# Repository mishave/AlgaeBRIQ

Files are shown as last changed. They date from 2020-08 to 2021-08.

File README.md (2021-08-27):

# BRIQ Algae PBR
Algae photobioreactor(PBR) platform - Focused on algae as potential food sources or means for small scale carbon sequestration, apposed to biofuel, the project hopes to provide the starting point for collaboration, to bring PBR technology out of the lab and into our everyday lives. 

*WORK IN PROGRESS*
<p align="center">
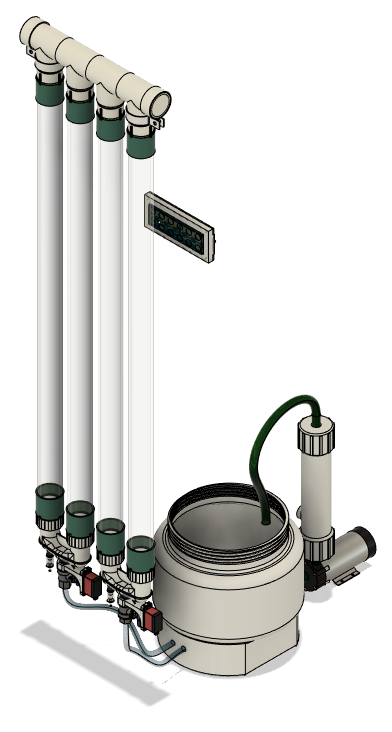
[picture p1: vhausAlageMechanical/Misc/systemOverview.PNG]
  
</p>

## Design Overview :v:
### Cultivation
- Close loop design
- 5.8L capacity
- Sensing: 
  - pH
  - Water Temperature
  - Dissolved Oxygen
  - Lux
  - Water Level
  - External Temperature & Humidity
- Control:
  - pH up/Down
  - Culture Temperature
  - Light Cycle & Intensity

### Harvesting
- 15L capacity
- crossflow filter

### Software
- Home Assistant
  - Mosquitto broker - MQTT
  - AppDaemon - Python
- Google Sheets API

## Next Steps :point_up:
- [ ] Transfer drawings from Eagle to KiCad
- [ ] Add heating to tempreture control
- [ ] Remove Arduino Mega

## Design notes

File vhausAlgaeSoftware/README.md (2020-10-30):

# Vhaus.Tech Algae Software
Software based Home Assistant using RaspberryPi 4.

*WORK IN PROGRESS*

<p align="center">
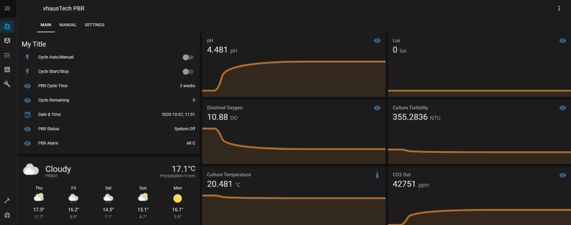
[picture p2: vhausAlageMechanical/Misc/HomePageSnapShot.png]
  
</p>

It is recommended to set up Home Assistant first [Home Assistant Setup Guide](https://github.com/mishave/vhausAlgae/tree/master/vhausAlgaeSoftware/Home%20Assistant%20SetUp)
## Software 
### Setup
The software will require:
- 1 RasberryPi
- 3 ESP32 WROOMS 32D Microcontrollers
- Arduino Mega
- Sensor PCB
- Brain PCB

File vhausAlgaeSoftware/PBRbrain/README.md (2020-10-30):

# Vhaus.Tech Algae Brain
Brains of the operation - The brain ESP board is what houses the code to run routines.

*WORK IN PROGRESS*

## Overview
### Required Parts
- ESP32-WROOMS-32D (ESP_Devkitc_v4)
- Arduino Mega (Looking to make obsolete, in v2.0)

### Software
- Arduino IDE - [Arduino IDE Download Link](https://www.arduino.cc/en/software)

### Required Libraries
#### ESP Board
- ArduinoJson.h
- WiFi.h
- PubSubClient.h
- WiFiManager.h

#### Arduino Mega Board
- ArduinoJson.h
- VarSpeedServo.h

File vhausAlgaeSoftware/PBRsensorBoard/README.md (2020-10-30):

# Vhaus.Tech Algae Sensor
It has a sixth sense - The Sensor board is what reads and communicates the data

*WORK IN PROGRESS*

## Overview
### Required Parts
- ESP32-WROOMS-32D (ESP_Devkitc_v4)

### Software
- Arduino IDE - [Arduino IDE Download Link](https://www.arduino.cc/en/software)

### Required Libraries
#### ESP Board
- SparkFun_Qwiic_Humidity_AHT20.h
- Adafruit_Sensor.h
- Adafruit_TSL2591.h
- SparkFun_Qwiic_Humidity_AHT20.h
- ArduinoJson.h
- WiFi.h
- PubSubClient.h
- WiFiManager.h
- Wire.h
- OneWire.h

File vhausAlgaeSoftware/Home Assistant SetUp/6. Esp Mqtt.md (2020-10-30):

###### 1	Add Esp Boards
Add to Additional Boards Mangaer URLS:
(File>Preferences)
 - https://dl.espressif.com/dl/package_esp32_index.json
Open Boards Manager and Add:
- esp32 by Espressif Systems

###### 2 Add Libraries
Include Libaries - From Library Manager:
 - PubSubClient by Nick
 - PageBuilder by Hieromon Ikasamo
 - WifiManager by tzapu

###### 3 Using The Following Test Code
Make sure you:
 - const char* mqtt_server = "192.168.0.200"; //set to your Home Assistant IP
 - const char *HA_USER = "Your HA Login"; //Set to your Home Assistant Login
 - const char *HA_PASS = "Your HA Password"; //Set to your Home Assistant Password

 Select from Tools your board:
  - ESP32 Dev Module
  - Select Comm Port - plug in and unplug to determine
  - verify and upload

Confirm that it has been uploaded via serial monitor, log with help to confirm it has worked.

```

#include <WiFi.h>
#include <PubSubClient.h>
//needed for library
#include <DNSServer.h>
#include <ESP8266WebServer.h>
#include <WiFiManager.h>         //https://github.com/tzapu/WiFiManager

// MQTT Network
const char* mqtt_server = "192.168.0.200"; //Set to you HA IP. recommend setting home assistant a a static IP
WiFiClient espClient;
PubSubClient client(espClient); // Setup MQTT client
const byte SWITCH_PIN = 0;           // Pin to control the light with
const char *ID = "Moisture_1";  // Name of our device, must be unique
const char *TOPIC = "Moisture_Sensor";  // Topic to subcribe to

bool state = 0;
String switch1;
String strTopic;
String strPayload;
int SwitchedPin = 0;

// Home Assistant Credentials
const char *HA_USER = "Your HA Login";
const char *HA_PASS = "Your HA Password";

// Moisture sensor
const float AirValue = 4095.0;   //you need to replace this value with Value_1
const float WaterValue = 1999.0;  //you need to replace this value with Value_2
const int SensorPin = 15;
float soilMoistureValue = 0.0;
float soilmoisturepercent = 0.0;
int lastreading = 0;
int timervalue = 200;

void setup_wifi() {
  Serial.print("\nConnecting to ");

  //WiFiManager
  //Local intialization. Once its business is done, there is no need to keep it around
  WiFiManager wifiManager;
  Serial.println("started");
  //reset saved settings

  //wifiManager.resetSettings();
  wifiManager.setCustomHeadElement("<style>html{filter: invert(40%); -webkit-filter: invert(40%);}</style>");
  WiFiManagerParameter custom_text("<p>This is just a text paragraph</p>");
  wifiManager.addParameter(&custom_text);
  //set custom ip for portal
  //wifiManager.setAPStaticIPConfig(IPAddress(10,0,1,1), IPAddress(10,0,1,1), IPAddress(255,255,255,0));

  //fetches ssid and pass from eeprom and tries to connect
  //if it does not connect it starts an access point with the specified name
  //here  "AutoConnectAP"
  //and goes into a blocking loop awaiting configuration
  //set custom ip for portal
  wifiManager.setAPStaticIPConfig(IPAddress(100, 100, 100, 100), IPAddress(100, 100, 100, 100), IPAddress(255, 255, 255, 0));
  //wifiManager.setSTAStaticIPConfig(IPAddress(192,168,0,99), IPAddress(192,168,0,1), IPAddress(255,255,255,0));

  wifiManager.autoConnect();
  //or use this for auto generated name ESP + ChipID
  //wifiManager.autoConnect();

  while (WiFi.status() != WL_CONNECTED) { // Wait for connection
    delay(500);
    Serial.print(".");
  }

  //if you get here you have connected to the WiFi
  Serial.println();
  Serial.println("WiFi connected");
  Serial.print("IP address: ");
  Serial.println(WiFi.localIP());
}

// Reconnect to client
void reconnect() {
  // Loop until we're reconnected
  while (!client.connected()) {
    Serial.print("Attempting MQTT connection...");
    // Attempt to connect
    if (client.connect(ID, HA_USER, HA_PASS)) {
      Serial.println("connected");
      Serial.print("Publishing to: ");
      Serial.println(TOPIC);
      Serial.println('\n');

    } else {
      Serial.println(" try again in 5 seconds");
      // Wait 5 seconds before retrying
      delay(5000);
    }
  }
}

void callback(char* topic, byte* payload, unsigned int length) {
  payload[length] = '\0';
  strTopic = String((char*)topic);
  if (strTopic == "ha/switch1")
  {
    switch1 = String((char*)payload);
    if (switch1 == "ON")
    {
      Serial.println("ON");
      digitalWrite(SwitchedPin, HIGH);
    }
    else
    {
      Serial.println("OFF");
      digitalWrite(SwitchedPin, LOW);
    }
  }
}

void setup() {
  // put your setup code here, to run once:
  Serial.begin(115200);

  pinMode(SWITCH_PIN, INPUT); // Configure SWITCH_Pin as an input
  digitalWrite(SWITCH_PIN, HIGH); // enable pull-up resistor (active low)
  delay(100);
  setup_wifi(); // Connect to network
  client.setServer(mqtt_server, 1883);
  client.setCallback(callback);
}

void loop() {
  if (!client.connected()) { // Reconnect if connection is lost
    reconnect();
  }
  client.loop();

  // if the switch is being pressed
  if (digitalRead(SWITCH_PIN) == 0) {

    state = !state; //toggle state
    if (state == 1) {// ON

      //client.publish(TOPIC, "on");
      //Serial.println((String)TOPIC + " => on");
    }
    else {// OFF

      //client.publish(TOPIC, "off");
      //Serial.println((String)TOPIC + " => off");
    }

    while (digitalRead(SWITCH_PIN) == 0) {// Wait for switch to be released

      delay(20);
    }
  }

  moisture_sensor();

}

void moisture_sensor() {

  if (!client.connected())  // Reconnect if connection is lost
  {
    reconnect();
  }
  client.loop();

  soilMoistureValue = 255;
  Serial.println(soilMoistureValue);
  soilmoisturepercent = 100.0 * (soilMoistureValue - AirValue) / (WaterValue - AirValue);   //map(soilMoistureValue, AirValue, WaterValue, 0, 100);

  if (lastreading != soilmoisturepercent) {
    if (soilmoisturepercent > 100)
    {
      soilmoisturepercent = 100;
      lastreading = soilmoisturepercent;
    }
    else if (soilmoisturepercent < 0)
    {
      soilmoisturepercent = 0;
      Serial.println(soilMoistureValue);
    }
    else if (soilmoisturepercent >= 0 && soilmoisturepercent <= 100)
    {
      Serial.print(soilMoistureValue);
    }
  }
  soilmoisturepercent = random(45,100);
  client.publish(TOPIC, String(soilmoisturepercent).c_str());
  Serial.print ("MQTT Published");
}
```
###### 4 Connect ESP to WIFI
With ESP plugged in (suggest using a phone), open wifi and find ESP network and connect.
Will promt a login window, use this to add esp to your wifi network. if window does not pop up, open browser and go to 100.100.100.100

Choose network to connect to and type password. 

Once done it will save the network and password so you can upload code without having to do it again.

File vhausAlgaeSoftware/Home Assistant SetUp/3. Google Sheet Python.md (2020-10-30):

## *** CRED.JSON FILE HAS TO BE LOCATED IN /usr/share/hassio/share and label '/share/youfilename.json)

## 1 Add Google Python Packages tToo Suppervisor:
```
system_packages: []
python_packages:
  - hass-apps
  - gspread
  - oauth2client
  - apiclient
init_commands: []
```
## Setup app.yaml to see your file
you can do this after of before but you need to know what your .py file is to be called as well as your class to be called, for example:
```diff
---                         # At the top of the file, doesnt need to be done each time you make a new setup
upDateSheet:                # this can be called what ever you like
    module: upDateMySheet   # this is what your python file .py has to be named
    class: upDateTheSheet   # this is the class to be called inside the .py
```
## Create your .py file and name the same as the module above i.e upDateMySheet.py
```diff
import appdaemon.plugins.hass.hassapi as hass
import gspread
from oauth2client.service_account import ServiceAccountCredentials
import datetime
import json

#
# description of what your doing
#
# Args:
#

class TurnOffPBR(hass.Hass):

    def initialize(self):
        self.listen_state(self.pbr_off_turn_off,"input_boolean.switch1", new='on', old='off')
        
    def pbr_off_turn_off(self, entity, attribute, old, new, kwargs):
        self.run_in(self.search, 2)
        
        # use creds to create a client to interact with the Google Drive API
        scope = ['https://spreadsheets.google.com/feeds',
                 'https://www.googleapis.com/auth/drive']
        creds = ServiceAccountCredentials.from_json_keyfile_name('/share/NameThisYourCredFileName.json', scope) # change to name of your file
        client = gspread.authorize(creds)
        fmt = '%Y-%m-%d %H:%M:%S'
        d = datetime.datetime.now()
        d_string = d.strftime(fmt)
        
        val1 = self.get_state("input_boolean.switch1")
        val2 = "123"

        sheet = client.open("nameThisyouGoogleSheetName").sheet1   #change to name of your sheet
        
        row = [d_string,val1,val2]
        index = 1
        sheet.insert_row(row, index, value_input_option='USER_ENTERED')

    def search(self, kwargs):
        #self.set_textvalue("input_text.text1", "hello world")
        self.turn_off("input_boolean.switch1")
```
## Note You Need To Set Up Any Entities You Are Calling From Home Assistant
in this case we used `input_boolean.switch1` therefor to use it we need to make sure its in our configuration.yaml file.
```diff
#Boolean Switches to be used as control for system
input_boolean:
  switch1:
    initial: off
```

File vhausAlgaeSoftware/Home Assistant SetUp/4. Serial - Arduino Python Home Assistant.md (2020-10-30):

## For this Code a JSON Libary has been used and will need to be installed to work

## 1 Desktop	
- Install Arduino
    https://www.arduino.cc/en/main/software
    **does not have to be on pi, use what ever computer you will be programing on
- Select Sketch > Include Library > Manage Libraries
- In filter search search: JSON
- Select and install: ArduinoJSON by Benoit Blanchon
## 3 Browser	
- Format/Size/Determin JSON String to be sent using ArduinoJSON assistent
    https://arduinojson.org/v6/assistant/
## 4 Arduino - create and upload to Arduino
Example CODE
```diff
#include <ArduinoJson.h>
#include <SoftwareSerial.h>     //not needed, used to debug
SoftwareSerial portTwo(20, 21); //not needed, used to debug

void setup() {
    Serial.begin(9600);
    portTwo.begin(9600);        //not needed, used to debug
}

void loop() {
    UpdatePi();
    RecievePiUpdate();

void UpdatePi() {
    const size_t capacity = JSON_OBJECT_SIZE(4);
    DynamicJsonDocument doc(capacity);
    long randNumber1 = random(20,30);
    long randNumber2 = random(15,25);
    long randNumber3 = random(20,24);
    long randNumber4 = random(0,14);
	
    doc["b1"] = b3;
    doc["b2"] = randNumber2;
    doc["s1"] = randNumber3;
    doc["s2"] = randNumber4;
	
    serializeJson(doc, Serial);
    Serial.println();
}
	
void RecievePiUpdate() {
    const size_t capacity = JSON_OBJECT_SIZE(4) + 20;
    char json[capacity];
    DynamicJsonDocument doc(capacity);
    deserializeJson(doc, Serial);
    b3 = doc["b3"];
    float b4 = doc["b4"];
    long s3 = doc["s3"];
    long s4 = doc["s4"];
	
    serializeJson(doc, portTwo);  //Used only for debugging to a second arduino, not required
    portTwo.println();            //As above
}
```

## 4 RPI creata a .py file - will require addition libaries in supervisor to access serial
```diff
import appdaemon.plugins.hass.hassapi as hass
import datetime
import time
import serial
import json

class ArduinoPiComms(hass.Hass):
        
    def initialize(self):
        start_time = self.datetime() + datetime.timedelta(seconds=1)
        self.handle = self.run_every(self.run_every_Serial,start_time,1)

    def run_every_Serial(self, kwargs):
        # Call to Home Assistant to turn the porch light on
        ser  = serial.Serial(
        port = '/dev/ttyACM0',
        baudrate = 9600,
        timeout=1,
        parity=serial.PARITY_NONE,
        bytesize=serial.EIGHTBITS,
        stopbits=serial.STOPBITS_ONE
        )

    data = {}
    data = {
        b3:float(self.get_state("input_number.slider1")),
        b4:float(self.get_state("input_number.box1")),
        s3:13518,
        s4:13518,
        }
    data=json.dumps(data)

    if ser.isOpen():
        ser.write(data.encode('ascii'))
        ser.flush()
        try:
            incoming = ser.readline().decode("utf-8")
            doc1 = json.loads(incoming)
            self.set_value('input_number.dummy1', doc1["b1"])
            self.set_value('input_number.dummy2', doc1["b2"])
            self.set_value('input_number.dummy3', doc1["s1"])
            self.set_value('input_number.dummy4', doc1["s2"])
        except Exception as e:
            self.log("Error : try to parse an incomplete message")
            pass
        ser.close()
```
## 5 Include pySerial in Appdaemon
```
system_packages: []
python_packages:
  - hass-apps
  - pyserial
init_commands: []
```
## 6 Tell apps.yaml to run your .py file
you can do this after of before but you need to know what your .py file is to be called as well as your class to be called, for example:
```diff
---                         # At the top of the file, doesnt need to be done each time you make a new setup
ArduinoSerial:                # this can be called what ever you like
    module: ArduinoPiSerial.py   # this is what your python file .py has to be named
    class: ArduinoPiComms   # this is the class to be called inside the .py
```

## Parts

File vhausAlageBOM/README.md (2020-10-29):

# Vhaus.Tech Algae BOM:
https://bit.ly/2G91BCT

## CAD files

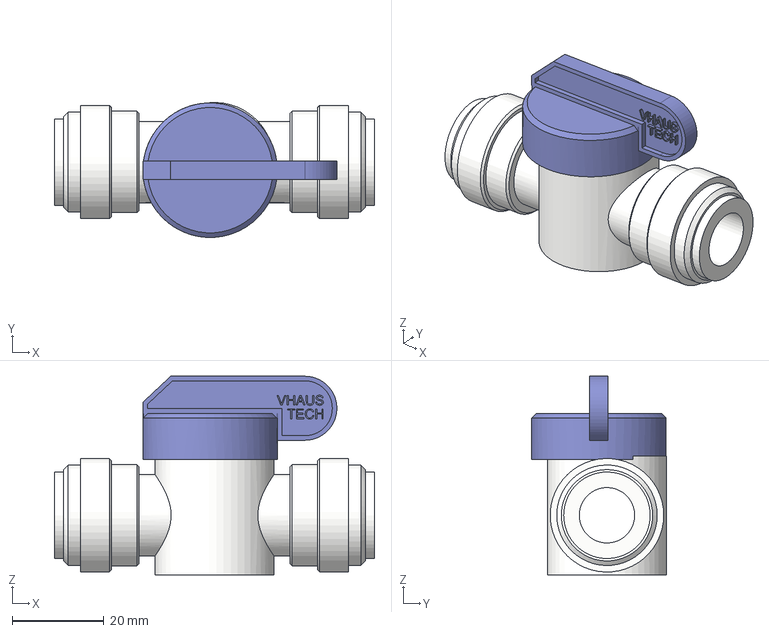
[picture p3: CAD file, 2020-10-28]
vhausAlageMechanical/3D Files/Ball Valves/12MM Shut Off Valve.step
69.9 x 29.5 x 43.4 mm
Base
Top Tap

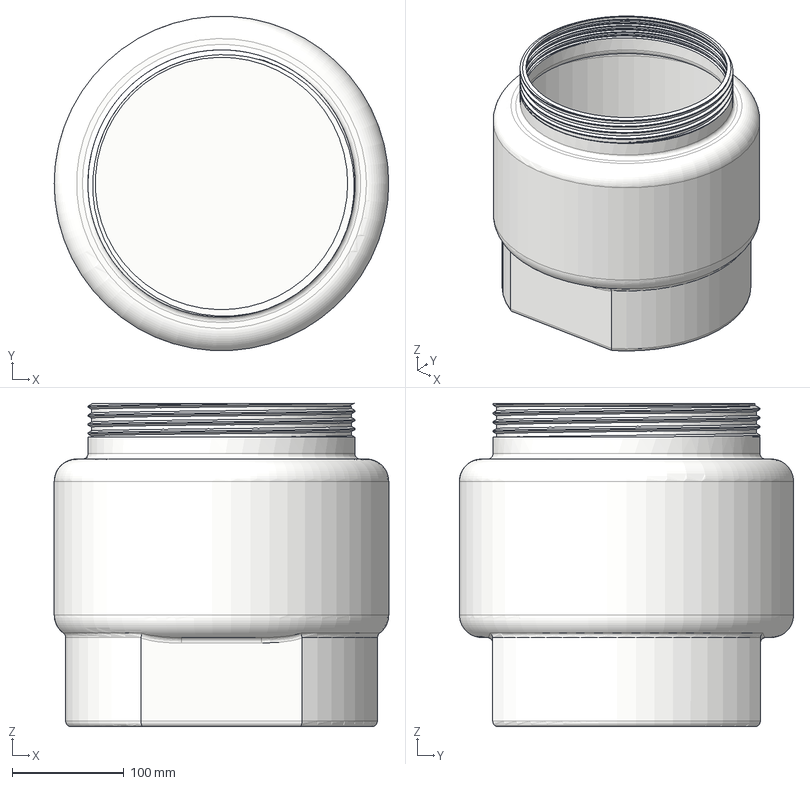
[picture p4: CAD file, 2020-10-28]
vhausAlageMechanical/3D Files/Bio Tube/Tank.step
300.0 x 299.5 x 290.0 mm

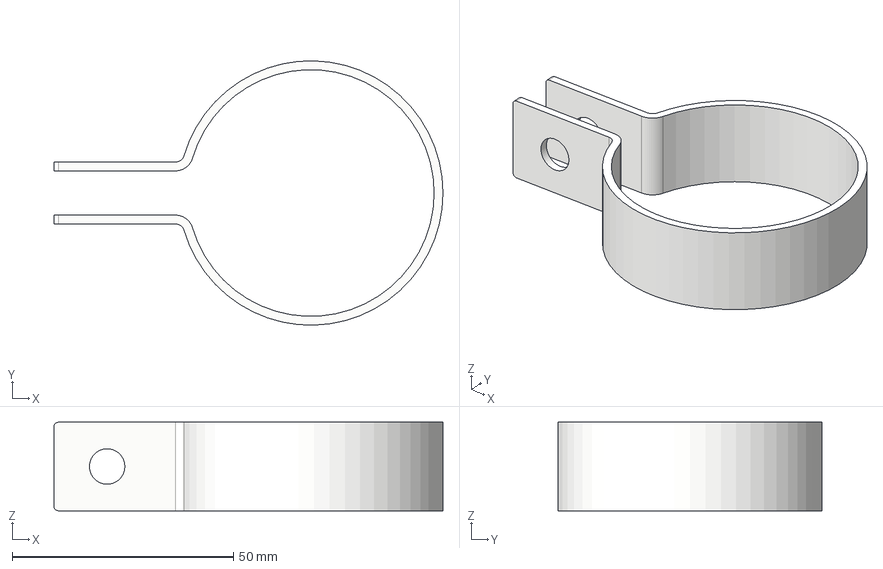
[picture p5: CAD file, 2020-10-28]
vhausAlageMechanical/3D Files/Brackets and Clips/Pipe Clamp.step
87.9 x 59.7 x 20.0 mm

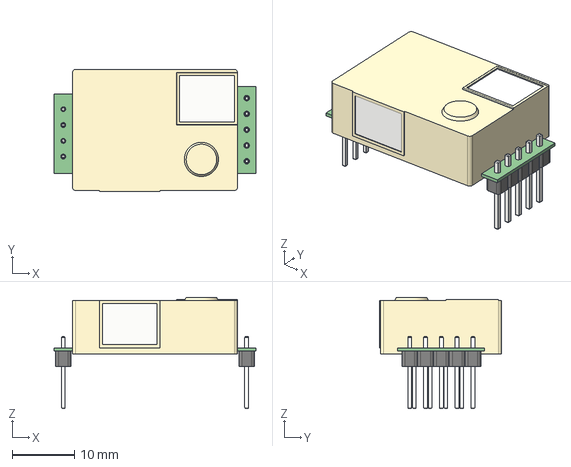
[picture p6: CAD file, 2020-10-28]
vhausAlageMechanical/3D Files/Electrical/MHZ19B.step
32.5 x 19.7 x 17.9 mm
spacer
MHZ19B_1

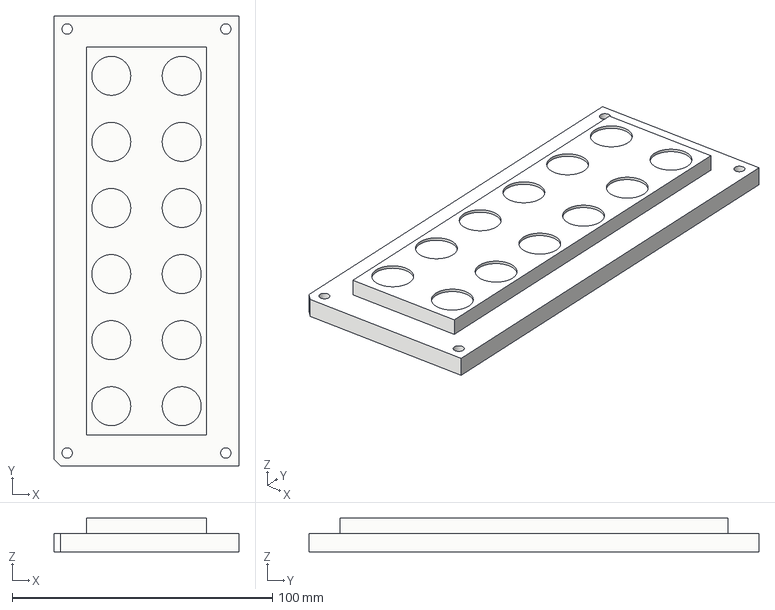
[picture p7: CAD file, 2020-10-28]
vhausAlageMechanical/3D Files/Lighting/Lens.step
71.0 x 173.0 x 13.0 mm

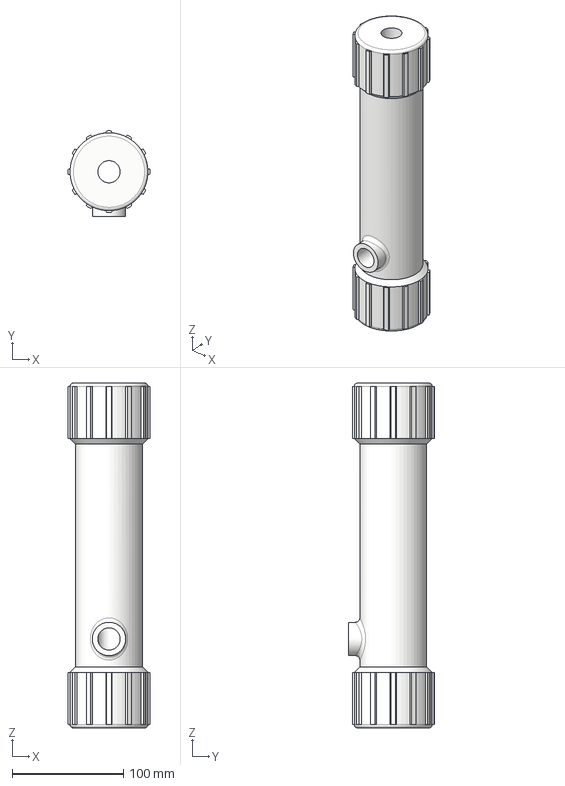
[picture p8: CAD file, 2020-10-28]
vhausAlageMechanical/3D Files/Other/Cross Flow Filter.step
73.7 x 76.8 x 310.0 mm

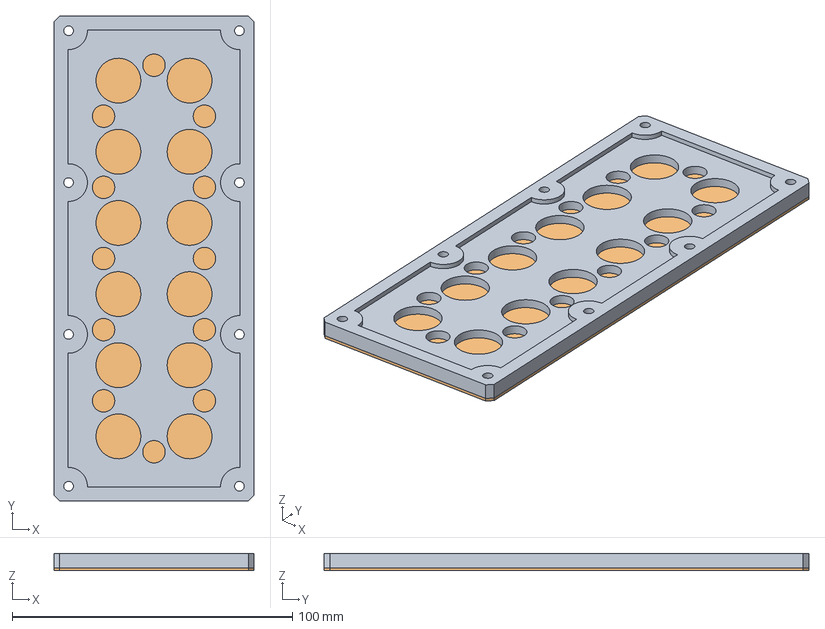
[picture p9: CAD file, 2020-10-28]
vhausAlageMechanical/3D Files/PCBs/LED.step
71.4 x 173.0 x 6.20 mm
Lens
PCB

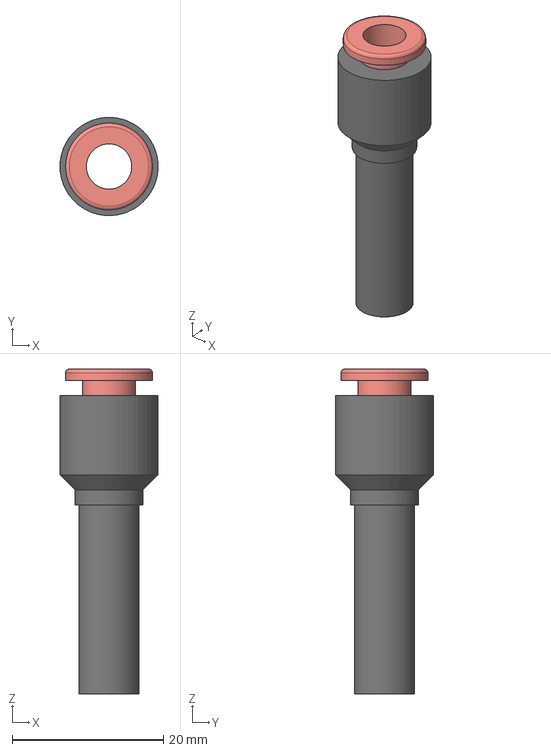
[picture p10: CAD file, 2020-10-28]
vhausAlageMechanical/3D Files/Punematics/Reducer 6-8.step
13.0 x 13.0 x 43.0 mm

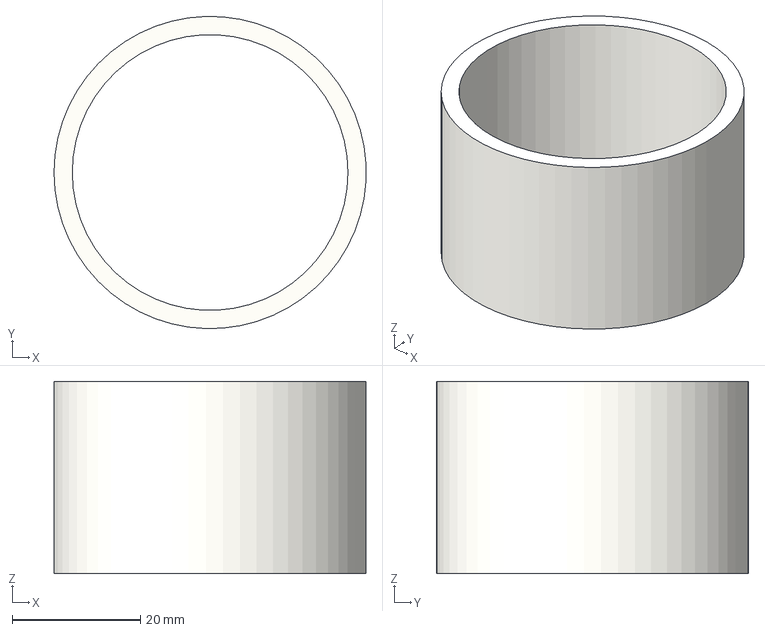
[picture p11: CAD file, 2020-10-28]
vhausAlageMechanical/3D Files/PVC/30mm Spacer - PVC 40mm Pressure Pipe Spacer.step
48.7 x 48.7 x 30.0 mm

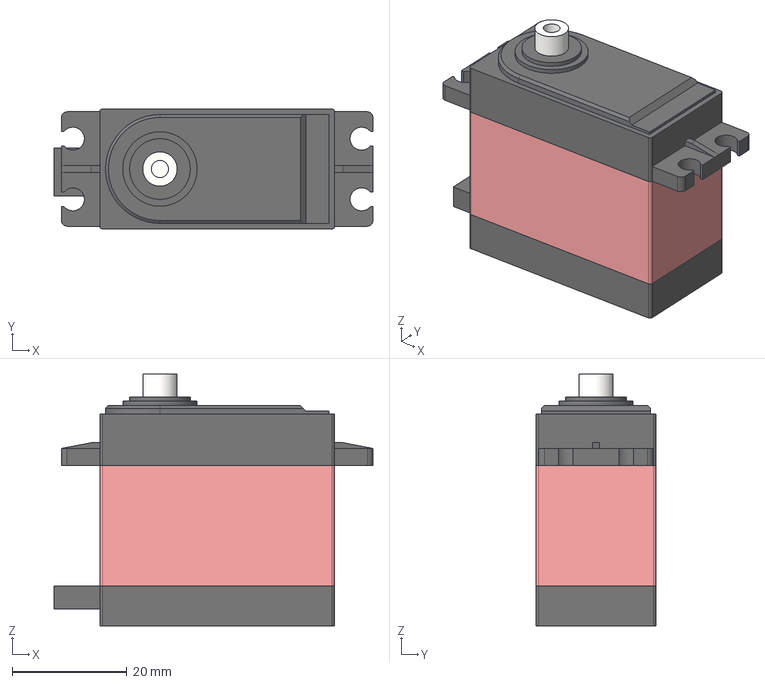
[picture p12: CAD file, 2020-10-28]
vhausAlageMechanical/3D Files/Servo Motors/PowerHD 20Kg 543015.step
55.7 x 21.0 x 44.0 mm

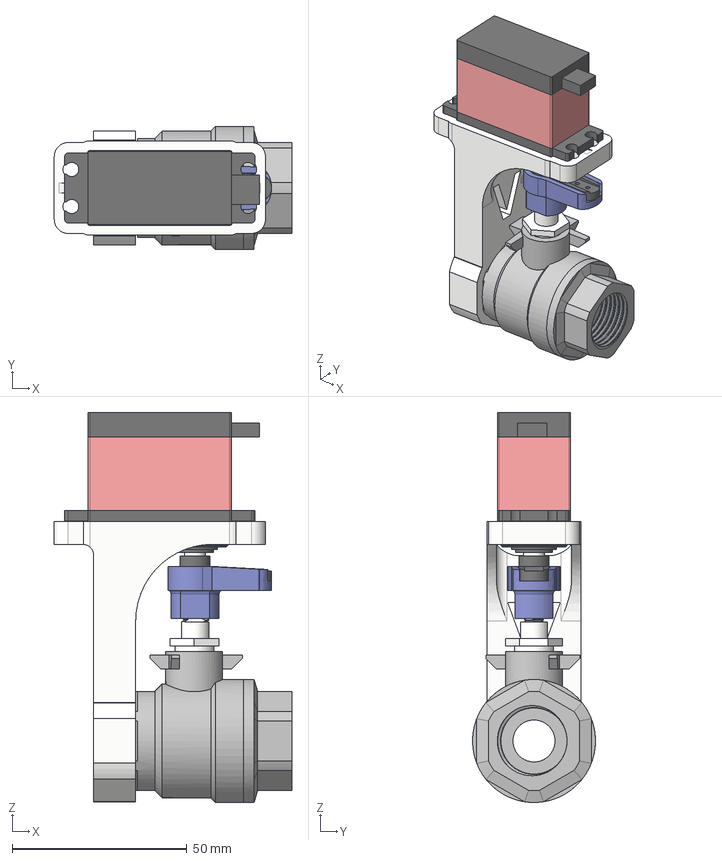
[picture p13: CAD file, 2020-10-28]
vhausAlageMechanical/3D Files/Sub Components/1 2 Flow Control Valve.step
67.9 x 35.2 x 111.5 mm
Servo 20Kg
Single Horn
Main Body
2nd Body
1 2 Horn Shoe
1 2 Main Body

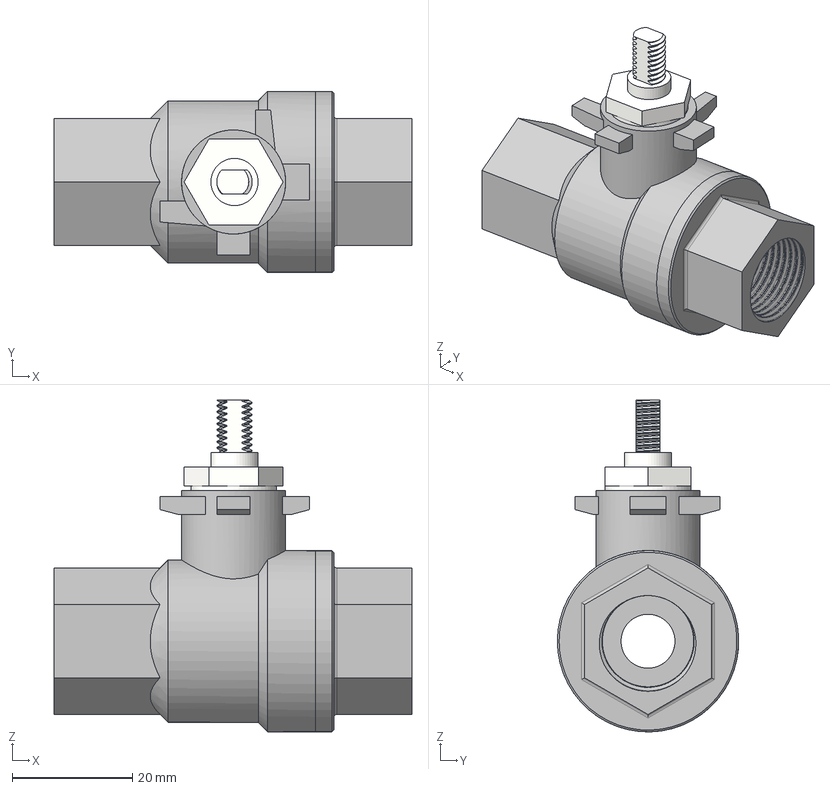
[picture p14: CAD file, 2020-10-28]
vhausAlageMechanical/3D Files/Ball Valves/3 8 Two Piece Ball Valve BVS3B L T.step
59.5 x 30.1 x 55.1 mm
3/8 Two Piece Ball Valve BVS3B-L-T
valve

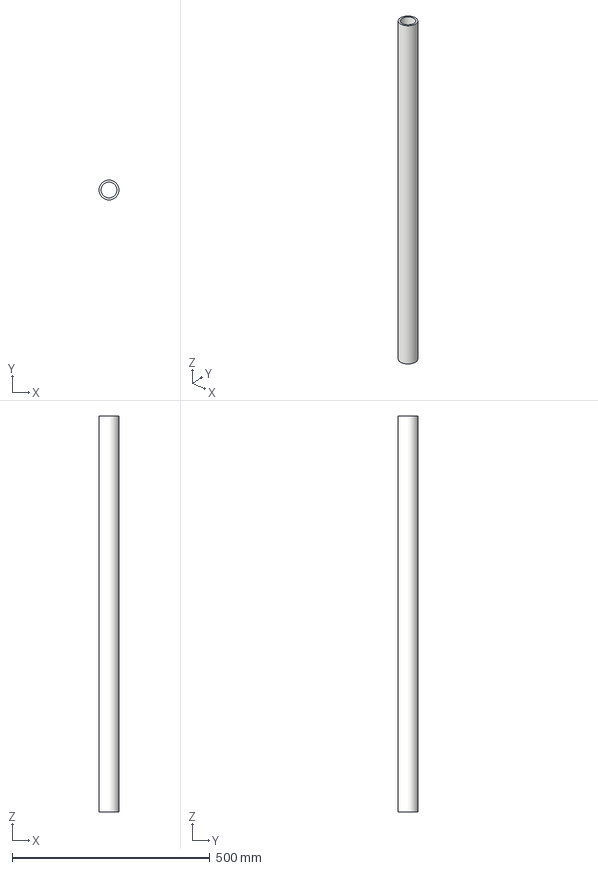
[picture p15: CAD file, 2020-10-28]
vhausAlageMechanical/3D Files/Bio Tube/Bio Tube.step
50.2 x 50.2 x 1000.0 mm

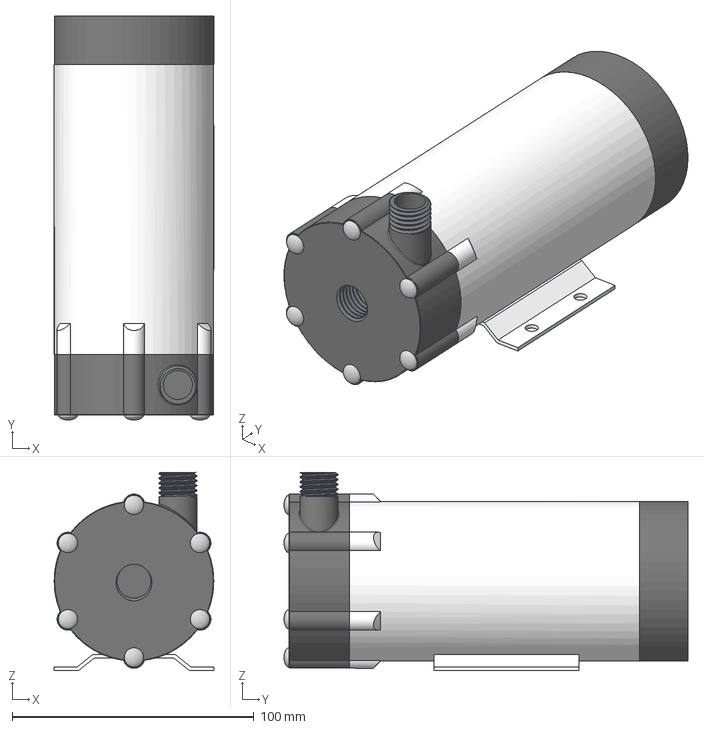
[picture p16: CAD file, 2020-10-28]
vhausAlageMechanical/3D Files/Electrical/Haarvest Pump.step
66.0 x 167.0 x 82.0 mm

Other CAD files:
vhausAlageMechanical/3D Files/PCBs/Sensor Board.step
vhausAlageMechanical/3D Files/Punematics/Check Valve.step
vhausAlageMechanical/3D Files/PVC/DWV PVC Adaptor Male Iron 40mm - Holman.step
vhausAlageMechanical/3D Files/Servo Motors/PowerHD Servo Horn (Half).step
vhausAlageMechanical/3D Files/Ball Valves/1 2 Two Piece Ball Valve BVS4B L T.step
vhausAlageMechanical/3D Files/Electrical/Dosing Pump.step
vhausAlageMechanical/3D Files/PVC/20mm Spacer - PVC 40mm Pressure Pipe Spacer.step
vhausAlageMechanical/3D Files/PVC/40mm DWV female Holman.step
vhausAlageMechanical/3D Files/PVC/40mm Short P Trap PVC Caroma U Bend Only.step
vhausAlageMechanical/3D Files/PVC/50mm End Cap DWV Holman.step
vhausAlageMechanical/3D Files/PVC/PVT 40mm Holman Tee Both Sides Cut.step
vhausAlageMechanical/3D Files/PVC/PVT 40mm Holman Tee One Side Cut.step
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

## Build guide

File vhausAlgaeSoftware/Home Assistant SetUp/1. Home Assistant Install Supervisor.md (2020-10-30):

###### 1	Install RPI OS
See RPI website for info
** add a blank text file to root dir called ssh - this will enable you to access via ssh https://www.raspberrypi.org/documentation/remote-access/ssh/README.md
** for wifi https://www.raspberrypi.org/documentation/configuration/wireless/headless.md
###### 2 Terminal	
`sudo raspi-config`
- Option 5 - Interfacing Options and then enable SSH, VNC, Serial etc.
- Option 7 Advanced Options, and then select Option A1 – expand file system
- Select Finish and reboot when prompted
###### 3 Terminal

```
sudo apt update && sudo apt dist-upgrade -y && sudo apt autoremove -y
sudo reboot
```

###### 4 Terminal

```	
sudo -i
apt-get install -y software-properties-common apparmor-utils apt-transport-https avahi-daemon ca-certificates curl dbus jq network-manager socat
systemctl disable ModemManager
systemctl stop ModemManager
curl -fsSL get.docker.com | sh
curl -sL "https://raw.githubusercontent.com/Kanga-Who/home-assistant/master/supervised-installer.sh" | bash -s -- -m raspberrypi4
```

*** if using a rpi3 replace 4 with 3
###### 5 Browser	
http://192.168.x.x:8123   - use the ip of your rpi
** chaneg to your RPI ip + can take up to 20 mins but once installed signup/login
###### 6 Browser	
***Once logged in and set up
- Open 'Supervisor' in side bar
- Add-on store
- Install AppDaemon 4
- Turn on Start on boot in side bar
- Start AppDaemon
- Install File Editor
- Turn on start on boot and show in side bar
- Start File Editor
	
Developed with the help off	
https://community.home-assistant.io/t/installing-home-assistant-supervised-on-raspberry-pi-os/201836

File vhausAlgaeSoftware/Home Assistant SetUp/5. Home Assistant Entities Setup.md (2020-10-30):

# Entites that can be set up in the configuration.yaml file
## input_boolean
These are used for switches as either on or off - https://www.home-assistant.io/integrations/input_boolean/
```diff
input_boolean:
  Switch1:              #name of entity
    initial: off        #intial state when first turned on
  Switch2:              #name of entity
    name: 2nd Switch    #friendly name that will show up on dashboard inplace of entity name
    icon: mdi:car       #set the icon to something else other then default - see: https://materialdesignicons.com/
    initial: off        #intial state when first turned on
```
when you call and input_boolean it will be address i.e. `input_boolean.Switch1`
In appdeamon this can be called by `self.get_state("input_boolean.pbr_auto_man")` This will return a 'on' or 'off'
to convert to a int/byte you can do the following:
```
Switch1_State = self.get_state("input_boolean.Switch1")
if Switch1_State == 'off':
    Switch1_State=0
else:
    Switch1_State=1
```
In appdaemon you can also set the sate by `self.turn_on('input_boolean.Switch1')` which you would call if a condition was met

## input_number
input_numbers are used to store values - https://www.home-assistant.io/integrations/input_number
these can either be displayed as a box or slider - see below.
This is also how you would make a dummy sensor, where the input_number is what updates the sensor value
```
input_number:
  slider1:
    name: Slider
    initial: 0
    min: 0
    max: 255
    step: 1
  box1:
    name: Numeric Input Box
    initial: 22
    min: -20
    max: 99
    step: 0.1
    mode: box
```
the minimum requirements are:
```
input_number:
  Slider1:
    min: -10
    max: 99
```
In appdaemon you can get the value using get state i.e `self.get_state("input_number.Slider1")` to convert from a string to a float for serial you can call `float(self.get_state("input_number.Slider1"))`
and like wise to set the value you can call `self.set_value('input_number.Slider1')`
** See 4. Serial - Arduino Python Home Assistant.md for more detail and use

## Sensors
Used to diplay your data on a chart etc. - https://www.home-assistant.io/integrations/sensor
```
sensor:
  - platform: template
    sensors:
      sensor1:
        friendly_name: "Water Sensor"
        value_template:"{{ states('input_number.Slider1') }}"
```
In the example above as the sensor is called from the input_number you do not need to use this in appdaemon, but weould follow the same process if needed.

###### To display a sensor in a time format you can add the following to the value template:

```diff
# NOTE:
# - define durations for the various UNITs of time
#   * modulus helps to reduce ""extras"" of the larger time units
# 
# - now build the string
#
# for each UNIT of time that's greater than 1:
#     if it's not the first loop iteration:
#         append "", "" to the string
#     else:
#         1. convert the DURATION to STR
#         2. split DURATION on "".""
#         3. append the left part (the whole number) to the string
#         4. append the UNIT to the string
#
# ...but if that's no UNITs, then we just started so
# set the string to ""just now""
#

sensor:
  - platform: template
    sensors:
#main Panel
      TimeInput:
        friendly_name: "Time"
        value_template: >-
          {%- set uptime  = states.input_number.TimeInput | round -%}
          {%- set sep     = ', ' -%}
          {%- set TIME_MAP = {
              'week': (uptime / 10080) % 10080,
               'day': (uptime / 1440) % 7,
              'hour': (uptime / 60) % 24,
            'minute': (uptime % 60)
          }
          -%}

          {%- for unit, duration in TIME_MAP.items() if duration >= 1 -%}
            {%- if not loop.first -%}
              {{ sep }}
            {%- endif -%}
              
            {{ (duration | string).split('.')[0] }} {{ unit }}

            {%- if duration >= 2 -%}
              s
            {%- endif -%}
          {%- endfor -%}

          {%- if uptime < 1 -%}
            0
          {%- endif -%}
```

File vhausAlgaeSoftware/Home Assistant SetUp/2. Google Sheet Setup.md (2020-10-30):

## Prerequisites:					
- Python 2.6 or greater - https://www.python.org/		
- The pip package management tool - https://pypi.org/project/pip/		
- A Google account - gmail/gsuite		
					
## 1 Terminal					
```
sudo pip install pip
sudo apt update && sudo apt dist-upgrade -y && sudo apt autoremove -y
sudo reboot
```	
## 2 Terminal					
`sudo pip install --upgrade google-api-python-client google-auth-httplib2 google-auth-oauthlib`			
					
## 3 Browser					
***Sign up if you havent already 				
- https://console.developers.google.com/				
- Select Create Project				
***Give project a name etc.				
- in search bar 'search for apis and services' search and enable the following:				
- Google Sheets API				
- Google Drive API				
					
- Use the home navigation icon in the top left and open 				
- APIs and Services > Credentials				
- .+Create Creditials				
- select Service Account				

	Role > Project > Editior				

	Leave blank and hit done				

	click on email name				

	Click Add Key > Create new Key				

	Select JSON and click CREATE				

	It will save a .JSON file to your computer, re name this and store it in the same dir where you will be running your python script from. If unkown save it in a safe place for later				
					
## 4 Browser					
- Create a new spread sheet and save it				
- Copy Service account email and share spread sheet (allow email to edit etc.)

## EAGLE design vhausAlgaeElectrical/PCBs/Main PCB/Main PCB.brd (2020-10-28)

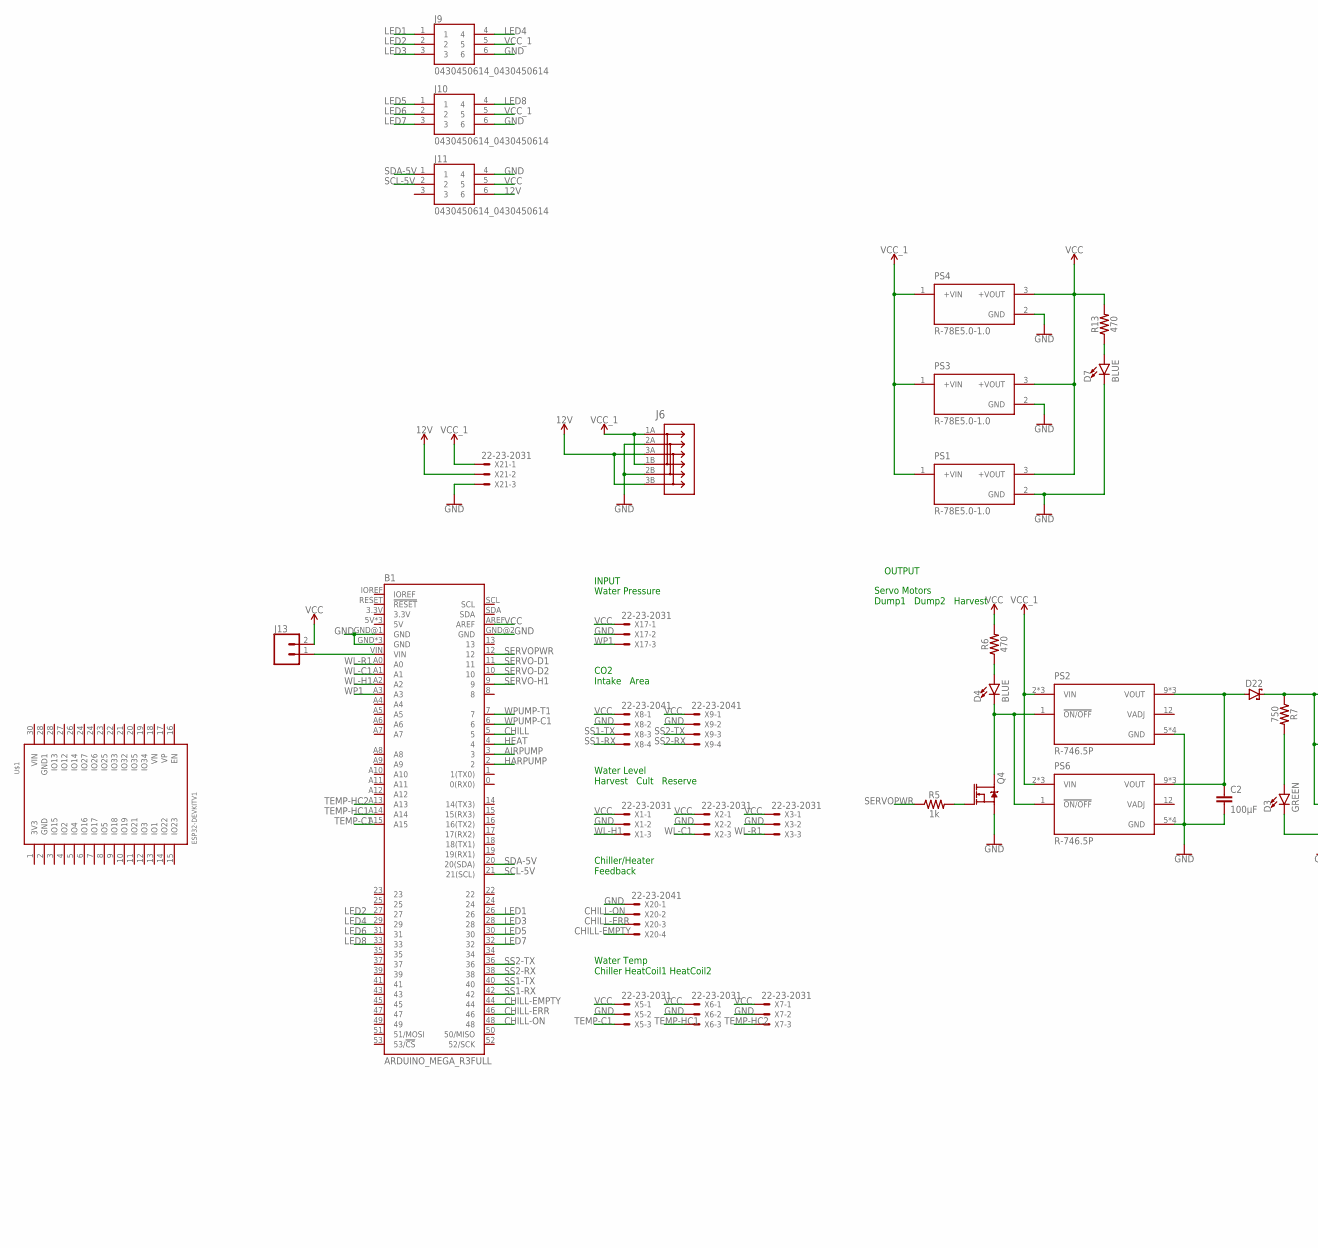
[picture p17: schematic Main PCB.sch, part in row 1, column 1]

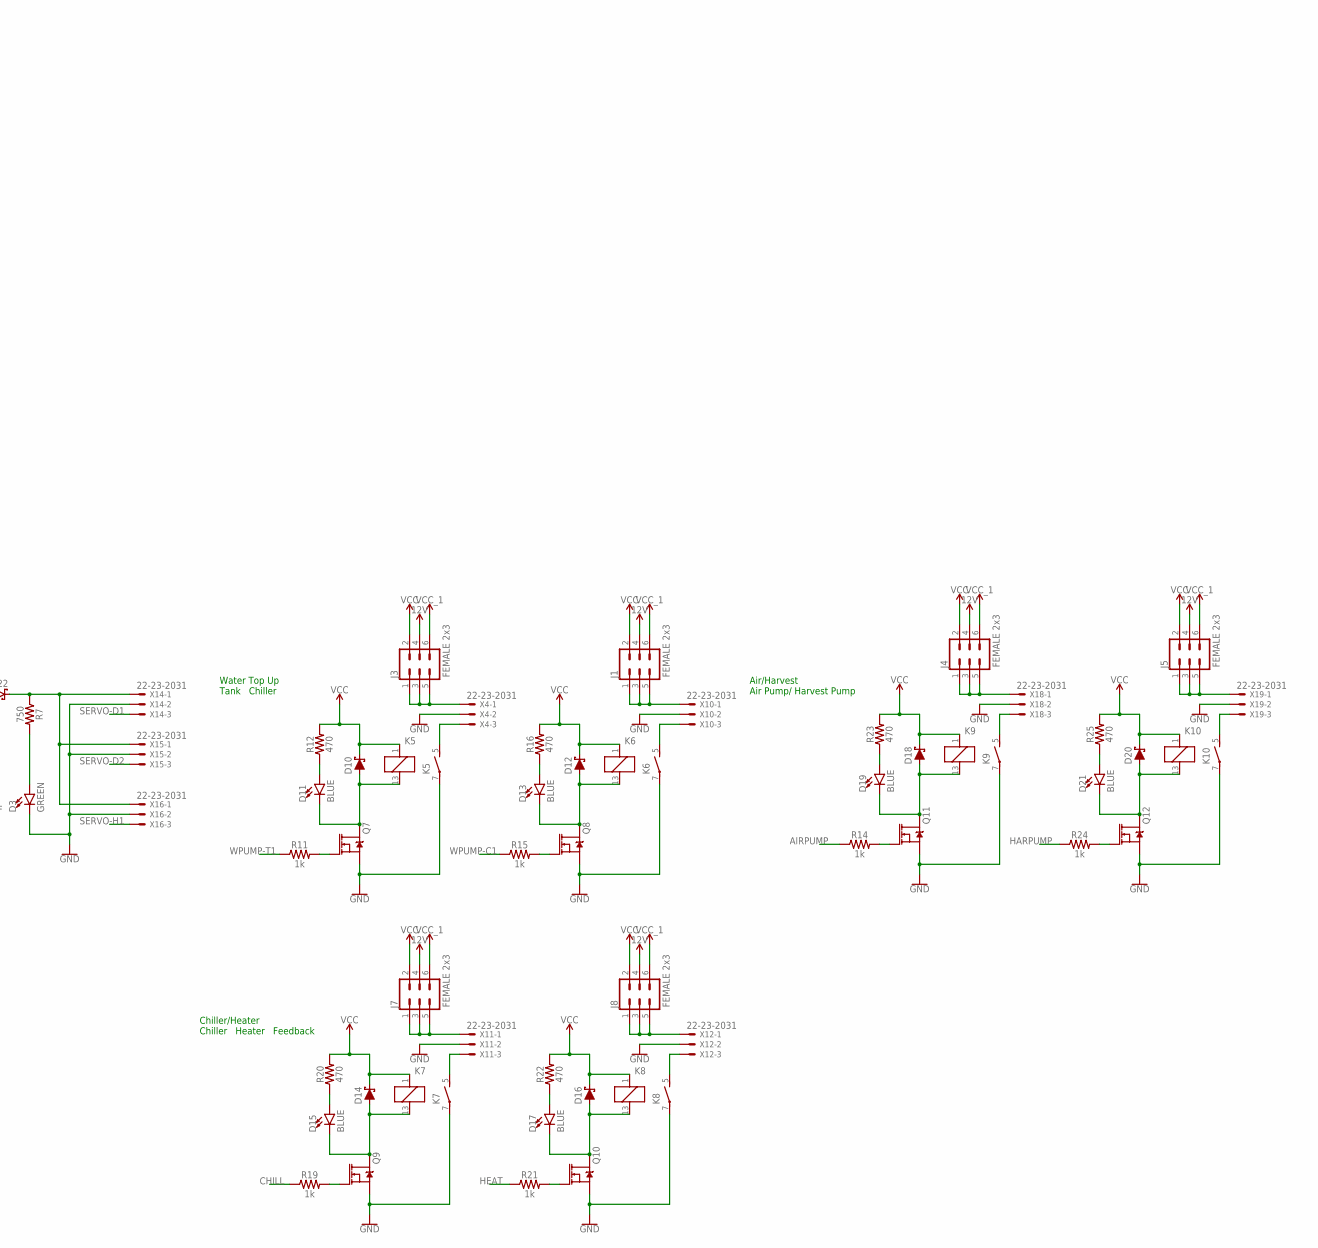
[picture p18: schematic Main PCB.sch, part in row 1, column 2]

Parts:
B1: ARDUINO_MEGA_R3FULL; ARDUINO_MEGA_NO_SILK
C2: 100µF; 0603
D3: GREEN; LED-0603
D4, D7, D11, D13, D15, D17, D19, D21: BLUE; LED-0603
D10, D12, D14, D16, D18, D20: 1A/23V/620mV; SOD-323
D22: SBRT20M60SP5-7SBRT20; DIO_PDS360-13
J1, J3, J4, J5, J7, J8: FEMALE 2x3; 2X3
J6: 1986711-3; CONN3_1986711-3_TEC
J9, J10, J11: 0430450614_0430450614; 0430450614_MOLEX_0430450614
J13: CONN_02; 1X02
K5, K6, K7, K8, K9, K10: G6D-1A-ASI5VDC; G6D
PS1, PS3, PS4: R-78E5.0-1.0; CONV_R-78E5.0-1.0
PS2, PS6: R-746.5P; CONV_R-746.5P
Q4, Q7, Q8, Q9, Q10, Q11, Q12: 220mA/50V/3.5Ω; SOT23-3
R5, R11, R14, R15, R19, R21, R24: 1k; 0603
R6, R12, R13, R16, R20, R22, R23, R25: 470; 0603
R7: 750; 0603
U$1: ESP32DEVKITV1; ESP32-DEVKITV1
X1, X2, X3, X4, X5, X6, X7, X10, X11, X12, X14, X15, X16, X17, X18, X19, X21: 22-23-2031
X8, X9, X20: 22-23-2041

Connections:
12V: J1.4, J3.4, J4.4, J5.4, J6.3A, J6.3B, J7.4, J8.4, J11.6, X21.2
AIRPUMP: B1.3, R14.1
CHILL: B1.5, R19.1
CHILL-EMPTY: B1.44, X20.4
CHILL-ERR: B1.46, X20.3
CHILL-ON: B1.48, X20.2
GND: B1.GND, B1.GND@1 (GND), B1.GND@2 (GND), B1.GND@3 (GND), B1.GND@4 (GND), C2.2, D3.C, D7.C, J6.2A, J6.2B, J9.6, J10.6, J11.4, K5.7, K6.7, K7.7, K8.7, K9.7, K10.7, PS1.2 (GND), PS2.5 (GND), PS2.6 (GND), PS2.7 (GND), PS2.8 (GND), PS3.2 (GND), PS4.2 (GND), PS6.5 (GND), PS6.6 (GND), PS6.7 (GND), PS6.8 (GND), Q4.2 (S), Q7.2 (S), Q8.2 (S), Q9.2 (S), Q10.2 (S), Q11.2 (S), Q12.2 (S), X1.2, X2.2, X3.2, X4.2, X5.2, X6.2, X7.2, X8.2, X9.2, X10.2, X11.2, X12.2, X14.2, X15.2, X16.2, X17.2, X18.2, X19.2, X20.1, X21.3
HARPUMP: B1.2, R24.1
HEAT: B1.4, R21.1
LED1: B1.26, J9.1
LED2: B1.27, J9.2
LED3: B1.28, J9.3
LED4: B1.29, J9.4
LED5: B1.30, J10.1
LED6: B1.31, J10.2
LED7: B1.32, J10.3
LED8: B1.33, J10.4
unnamed: B1.VIN, J13.1
unnamed: D4.C, PS2.1 (!ON/OFF), PS6.1 (!ON/OFF), Q4.3 (D)
unnamed: D4.A, R6.1
unnamed: Q4.1 (G), R5.2
unnamed: D3.A, R7.2
unnamed: D22.3 (C), R7.1, X14.1, X15.1, X16.1
unnamed: J1.1, J1.3, J1.5, X10.1
unnamed: J3.1, J3.3, J3.5, X4.1
unnamed: K8.5 (S), X12.3
unnamed: J4.1, J4.3, J4.5, X18.1
unnamed: J5.1, J5.3, J5.5, X19.1
unnamed: D10.A, D11.C, K5.13 (2), Q7.3 (D)
unnamed: D11.A, R12.1
unnamed: Q7.1 (G), R11.2
unnamed: D12.A, D13.C, K6.13 (2), Q8.3 (D)
unnamed: D13.A, R16.1
unnamed: Q8.1 (G), R15.2
unnamed: D14.A, D15.C, K7.13 (2), Q9.3 (D)
unnamed: D15.A, R20.1
unnamed: Q9.1 (G), R19.2
unnamed: D16.A, D17.C, K8.13 (2), Q10.3 (D)
unnamed: D17.A, R22.1
unnamed: Q10.1 (G), R21.2
unnamed: K7.5 (S), X11.3
unnamed: J7.1, J7.3, J7.5, X11.1
unnamed: D7.A, R13.1
unnamed: K5.5 (S), X4.3
unnamed: K6.5 (S), X10.3
unnamed: C2.1, D22.1 (A), D22.2 (A), PS2.9 (VOUT), PS2.10 (VOUT), PS2.11 (VOUT), PS6.9 (VOUT), PS6.10 (VOUT), PS6.11 (VOUT)
unnamed: J8.1, J8.3, J8.5, X12.1
unnamed: D18.A, D19.C, K9.13 (2), Q11.3 (D)
unnamed: D19.A, R23.1
unnamed: Q11.1 (G), R14.2
unnamed: D20.A, D21.C, K10.13 (2), Q12.3 (D)
unnamed: D21.A, R25.1
unnamed: Q12.1 (G), R24.2
unnamed: K10.5 (S), X19.3
unnamed: K9.5 (S), X18.3
SCL-5V: B1.21 (21(SCL)), J11.2
SDA-5V: B1.20 (20(SDA)), J11.1
SERVO-D1: B1.11, X14.3
SERVO-D2: B1.10, X15.3
SERVO-H1: B1.9, X16.3
SERVOPWR: B1.12, R5.1
SS1-RX: B1.42, X8.4
SS1-TX: B1.40, X8.3
SS2-RX: B1.38, X9.4
SS2-TX: B1.36, X9.3
TEMP-C1: B1.A15, X5.3
TEMP-HC1: B1.A14, X6.3
TEMP-HC2: B1.A13, X7.3
VCC: B1.AREF, D10.C, D12.C, D14.C, D16.C, D18.C, D20.C, J1.2, J3.2, J4.2, J5.2, J7.2, J8.2, J11.5, J13.2, K5.1, K6.1, K7.1, K8.1, K9.1, K10.1, PS1.3 (+VOUT), PS3.3 (+VOUT), PS4.3 (+VOUT), R6.2, R12.2, R13.2, R16.2, R20.2, R22.2, R23.2, R25.2, X1.1, X2.1, X3.1, X5.1, X6.1, X7.1, X8.1, X9.1, X17.1
VCC_1: J1.6, J3.6, J4.6, J5.6, J6.1A, J6.1B, J7.6, J8.6, J9.5, J10.5, PS1.1 (+VIN), PS2.2 (VIN), PS2.3 (VIN), PS2.4 (VIN), PS3.1 (+VIN), PS4.1 (+VIN), PS6.2 (VIN), PS6.3 (VIN), PS6.4 (VIN), X21.1
WL-C1: B1.A1, X2.3
WL-H1: B1.A2, X1.3
WL-R1: B1.A0, X3.3
WP1: B1.A3, X17.3
WPUMP-C1: B1.6, R15.1
WPUMP-T1: B1.7, R11.1

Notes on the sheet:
Water Level Harvest Cult Reserve
Water Top Up Tank Chiller
Water Temp Chiller HeatCoil1 HeatCoil2
CO2 Intake Area
Servo Motors Dump1 Dump2 Harvest
Water Pressure
INPUT
OUTPUT
Chiller/Heater Feedback
Chiller/Heater Chiller Heater Feedback
Air/Harvest Air Pump/ Harvest Pump

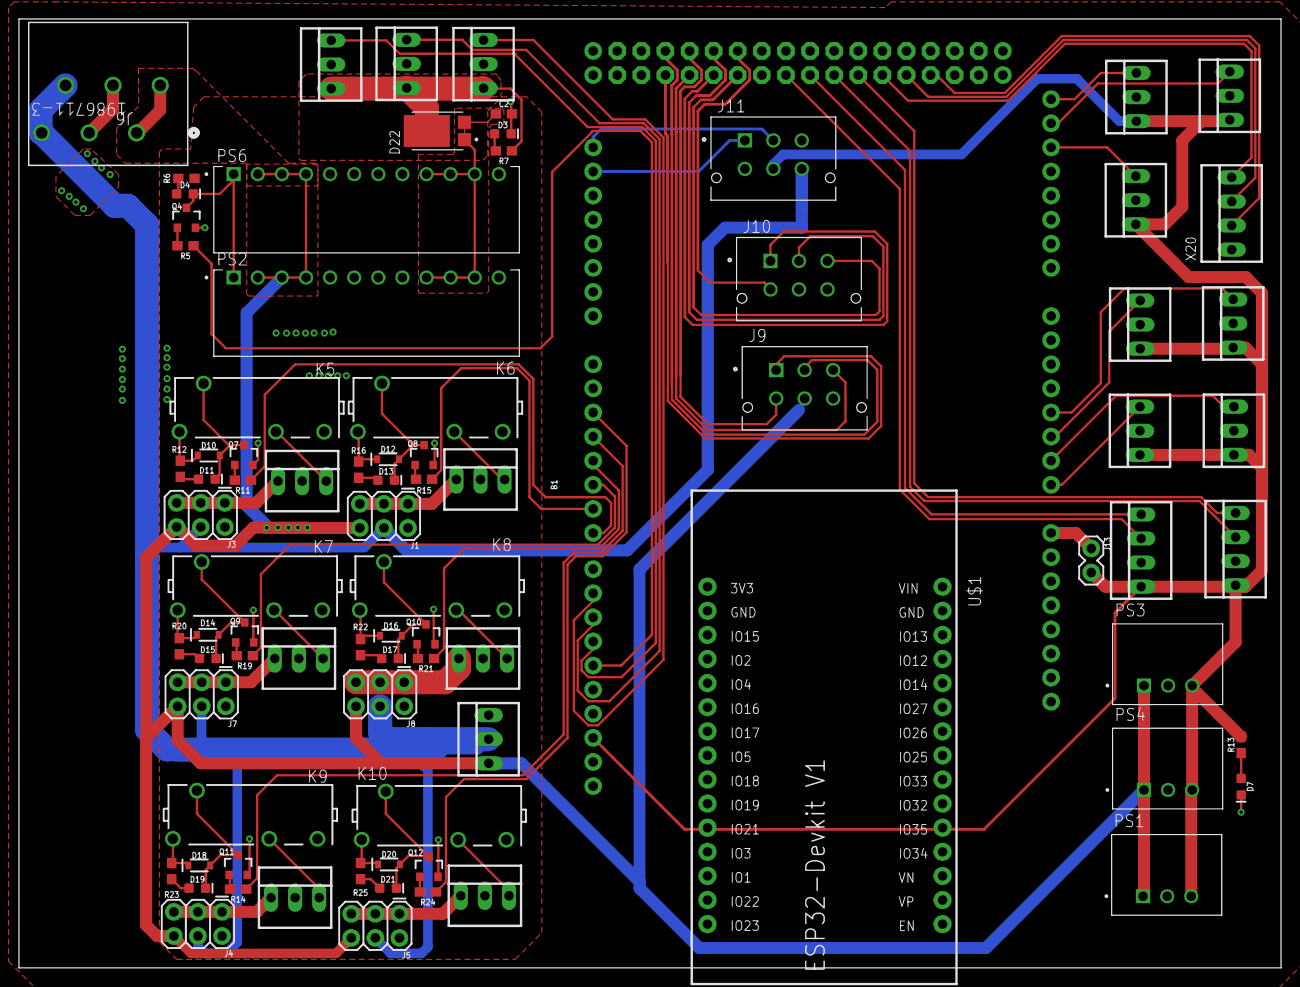
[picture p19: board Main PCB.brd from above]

Board: 2 copper layers, 133.0 x 100.0 mm, 84 parts (0 on the bottom side), 76 nets.

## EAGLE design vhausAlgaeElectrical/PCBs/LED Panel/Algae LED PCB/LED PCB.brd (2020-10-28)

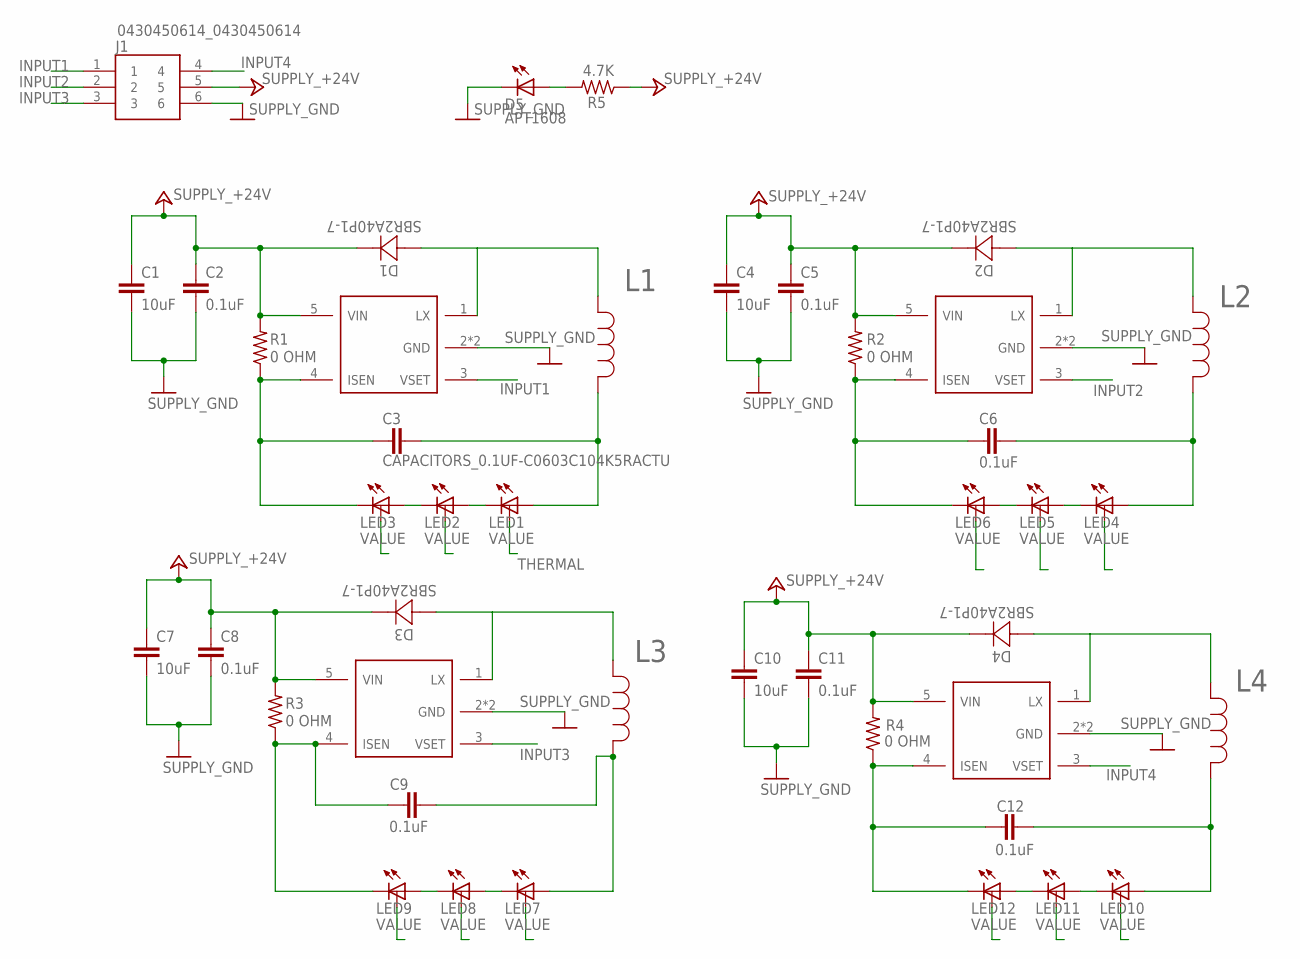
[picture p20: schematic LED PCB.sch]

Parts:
C1, C4, C7, C10: 10uF; CAPACITORS_C0805
C2, C5, C6, C8, C9, C11, C12: 0.1uF; CAPACITORS_C0603
C3: CAPACITORS_0.1UF-C0603C104K5RACTU; CAPACITORS_C0603
D1, D2, D3, D4: SBR2A40P1-7; DIODES_POWERDI123
D5: APT1608; DIODES_CHIPLED_0603
J1: 0430450614_0430450614; 0430450614_MOLEX_0430450614
L1, L2, L3, L4: INDUCTORS_100UH_BOURNES; INDUCTORS_IND_BOURNS_SDR1307
LED1, LED3, LED4, LED5, LED6, LED7, LED8, LED9, LED10, LED11, LED12: PFCEDU_V4_TOMASZEWSKI_LED_W/THERM-CREE_XP-E2; TOMASZEWSKI_CREE-XLAMP@1
LED2: TOMASZEWSKI_LED_W/THERM-CREE_XP-E2; TOMASZEWSKI_CREE-XLAMP@1
R1, R2, R3, R4: 0 OHM; RESISTORS_RC0603N
R5: 4.7K; RESISTORS_R1206
U$1, U$3, U$5, U$7: DRIVER-IC_AL8861

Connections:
+24V: C1.1, C2.1, C4.1, C5.1, C7.1, C8.1, C10.1, C11.1, D1.-, D2.-, D3.-, D4.-, J1.5, R1.2, R2.2, R3.2, R4.2, R5.1, U$1.5 (VIN), U$3.5 (VIN), U$5.5 (VIN), U$7.5 (VIN)
GND: C1.2, C2.2, C4.2, C5.2, C7.2, C8.2, C10.2, C11.2, D5.C, J1.6, U$1.2 (GND), U$1.44 (GND), U$3.2 (GND), U$3.44 (GND), U$5.2 (GND), U$5.44 (GND), U$7.2 (GND), U$7.44 (GND)
INPUT1: J1.1, U$1.3 (VSET)
INPUT2: J1.2, U$3.3 (VSET)
INPUT3: J1.3, U$5.3 (VSET)
INPUT4: J1.4, U$7.3 (VSET)
unnamed: C3.1, LED3.C, LED3.C@1 (C), R1.1, U$1.4 (ISEN)
unnamed: D1.+, L1.2, U$1.1 (LX)
unnamed: C9.2, L3.1, LED7.A, LED7.A@1 (A)
unnamed: C3.2, L1.1, LED1.A, LED1.A@1 (A)
unnamed: LED2.C, LED2.C@1 (C), LED3.A, LED3.A@1 (A)
unnamed: LED1.C, LED1.C@1 (C), LED2.A, LED2.A@1 (A)
unnamed: D3.+, L3.2, U$5.1 (LX)
unnamed: LED5.C, LED5.C@1 (C), LED6.A, LED6.A@1 (A)
unnamed: LED4.C, LED4.C@1 (C), LED5.A, LED5.A@1 (A)
unnamed: C12.1, LED12.C, LED12.C@1 (C), R4.1, U$7.4 (ISEN)
unnamed: D4.+, L4.2, U$7.1 (LX)
unnamed: LED8.C, LED8.C@1 (C), LED9.A, LED9.A@1 (A)
unnamed: LED7.C, LED7.C@1 (C), LED8.A, LED8.A@1 (A)
unnamed: LED11.C, LED11.C@1 (C), LED12.A, LED12.A@1 (A)
unnamed: LED10.C, LED10.C@1 (C), LED11.A, LED11.A@1 (A)
unnamed: C6.1, LED6.C, LED6.C@1 (C), R2.1, U$3.4 (ISEN)
unnamed: D2.+, L2.2, U$3.1 (LX)
unnamed: C6.2, L2.1, LED4.A, LED4.A@1 (A)
unnamed: C12.2, L4.1, LED10.A, LED10.A@1 (A)
unnamed: C9.1, LED9.C, LED9.C@1 (C), R3.1, U$5.4 (ISEN)
unnamed: D5.A, R5.2
THERMAL: LED1.THERM

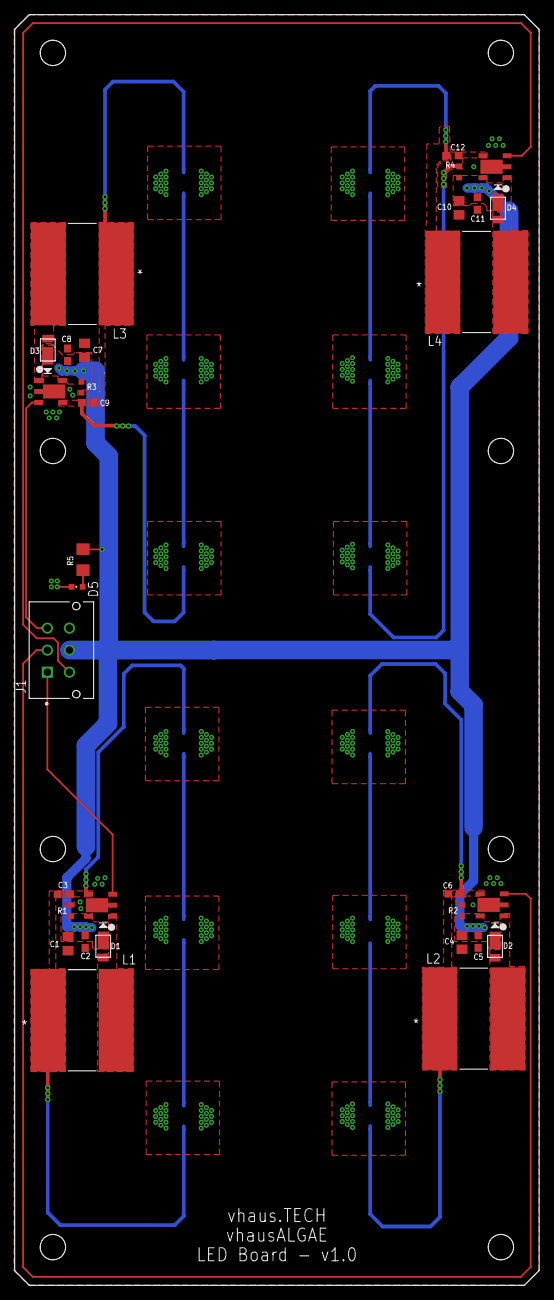
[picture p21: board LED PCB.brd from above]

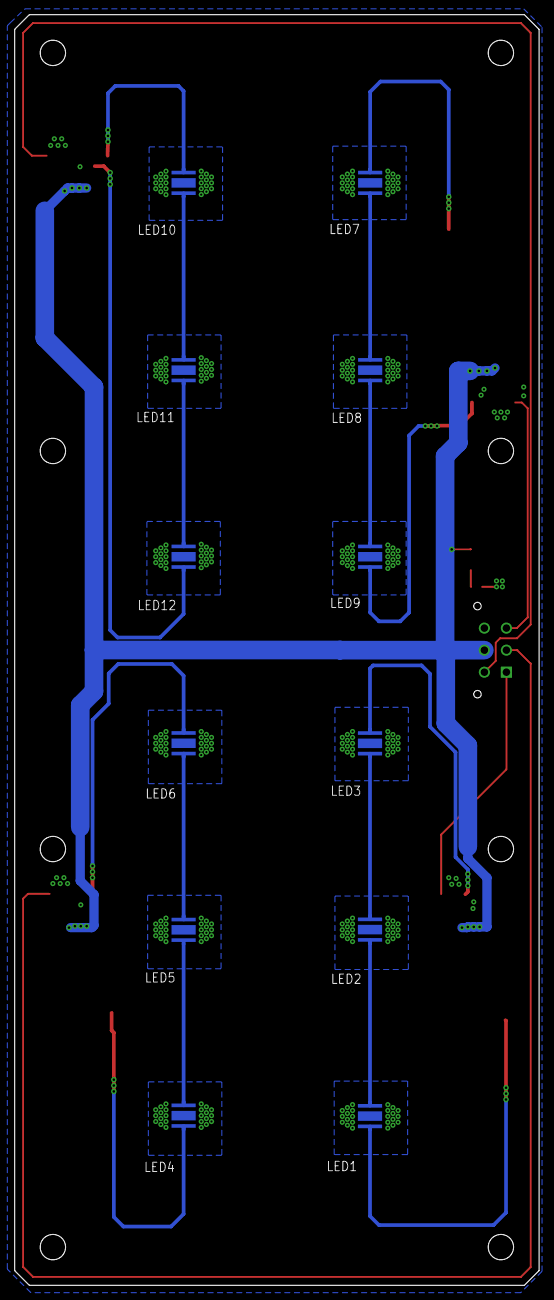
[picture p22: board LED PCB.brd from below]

Board: 2 copper layers, 71.4 x 173.0 mm, 43 parts (12 on the bottom side), 27 nets.

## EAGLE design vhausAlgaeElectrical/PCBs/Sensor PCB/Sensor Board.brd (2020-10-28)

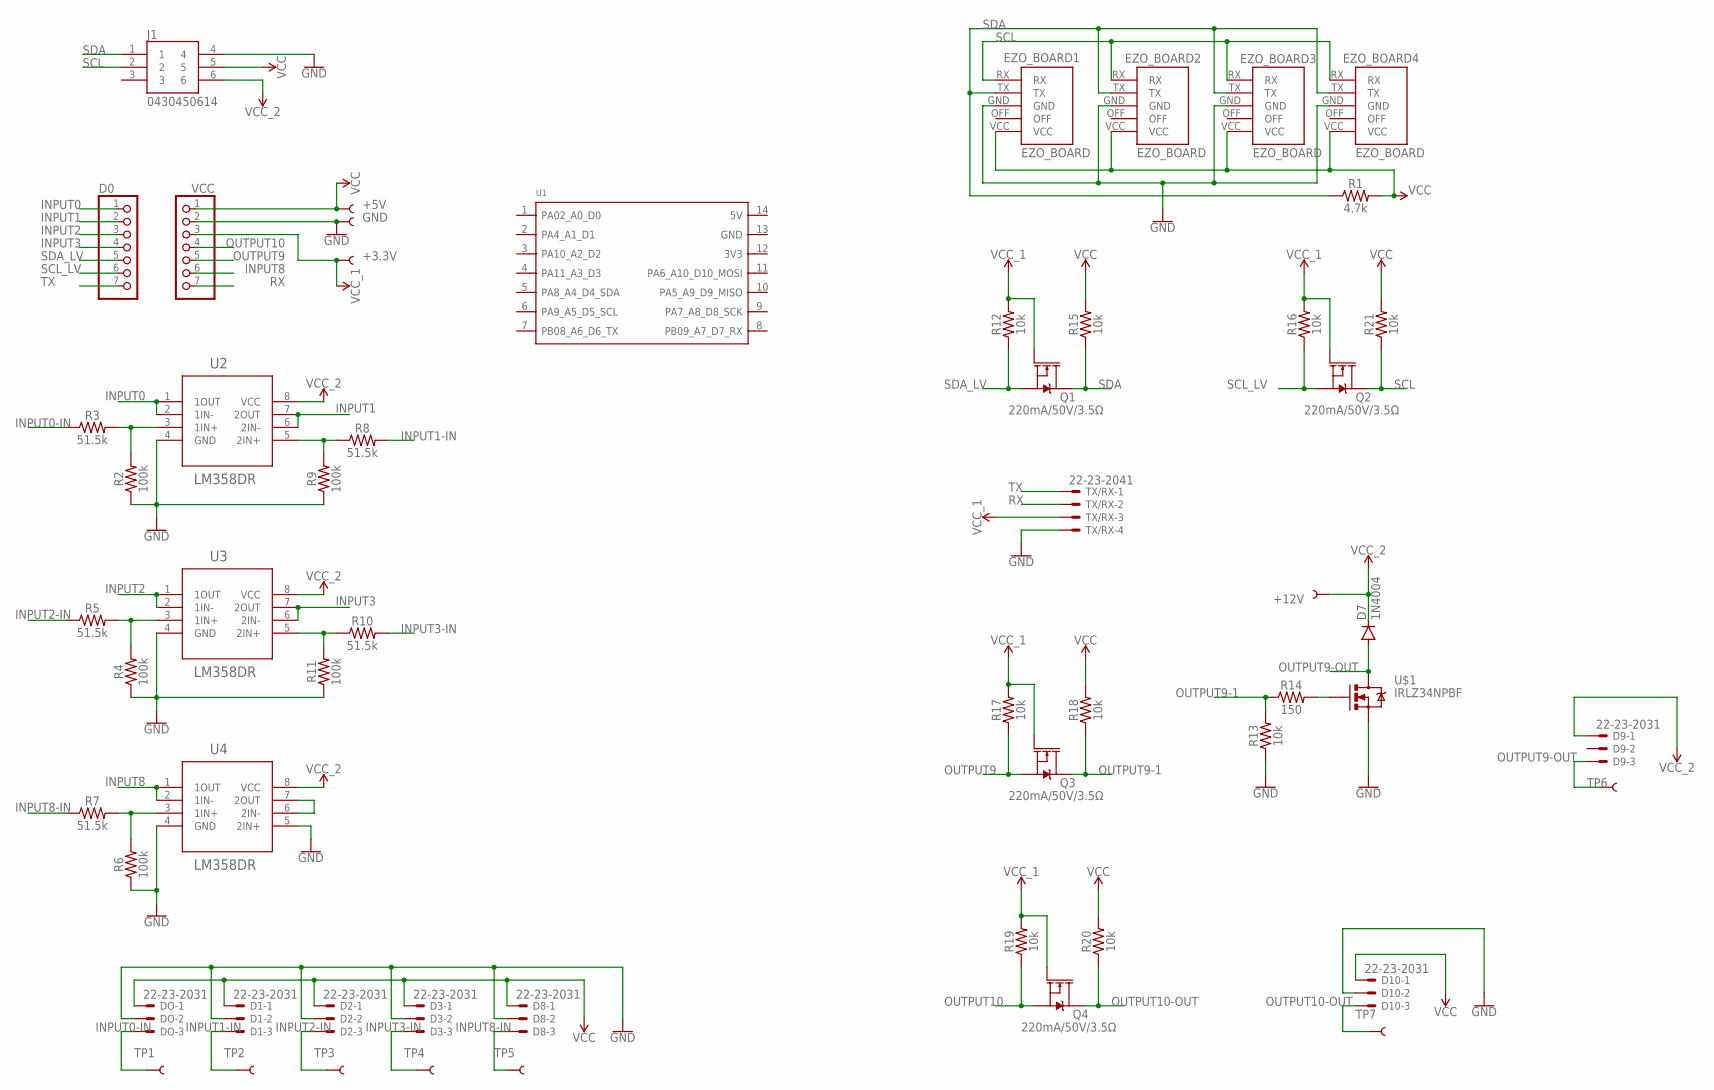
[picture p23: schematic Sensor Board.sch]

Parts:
+3.3V, +5V, +12V: TEST-POINTPOGO_PTH; 1X01_NO_SILK
D0: PINHD-1X7; 1X07
D1, D2, D3, D8, D9, D10: 22-23-2031
D7: 1N4004; DO41-10
DO: 22-23-2031
EZO_BOARD1, EZO_BOARD2, EZO_BOARD3, EZO_BOARD4: EZO_BOARD
GND: TEST-POINTPOGO_PTH; 1X01_NO_SILK
J1: 0430450614; MOLEX_0430450614
Q1, Q2, Q3, Q4: 220mA/50V/3.5Ω; SOT23-3
R1: 4.7k; 0603
R2, R4, R6, R9, R11: 100k; 0603
R3, R5, R7, R8, R10: 51.5k; 0603
R12, R13, R15, R16, R17, R18, R19, R20, R21: 10k; 0603
R14: 150; 0603
TP1, TP2, TP3, TP4, TP5, TP6, TP7: TEST-POINT2; PAD.02X.02
TX/RX: 22-23-2041
U1: MOUDLE-SEEEDUINO-XIAO; MOUDLE14P-2.54-21X17.8MM
U2, U3, U4: LM358DR; D8
U$1: IRLZ34NPBF; TO-220(2)
VCC: PINHD-1X7; 1X07

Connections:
GND: D1.2, D2.2, D3.2, D8.2, D10.2, DO.2, EZO_BOARD1.GND, EZO_BOARD2.GND, EZO_BOARD3.GND, EZO_BOARD4.GND, GND.1, J1.4, R2.1, R4.1, R6.1, R9.1, R11.1, R13.1, TX/RX.4, U2.4 (GND), U3.4 (GND), U4.4 (GND), U4.5 (2IN+), U$1.OUT (S), VCC.2
INPUT0: D0.1, U2.1 (1OUT), U2.2 (1IN-)
INPUT0-IN: DO.3, R3.1, TP1.1
INPUT1: D0.2, U2.6 (2IN-), U2.7 (2OUT)
INPUT1-IN: D1.3, R8.2, TP2.1
INPUT2: D0.3, U3.1 (1OUT), U3.2 (1IN-)
INPUT2-IN: D2.3, R5.1, TP3.1
INPUT3: D0.4, U3.6 (2IN-), U3.7 (2OUT)
INPUT3-IN: D3.3, R10.2, TP4.1
INPUT8: U4.1 (1OUT), U4.2 (1IN-), VCC.6
INPUT8-IN: D8.3, R7.1, TP5.1
unnamed: R2.2, R3.2, U2.3 (1IN+)
unnamed: R4.2, R5.2, U3.3 (1IN+)
unnamed: R6.2, R7.2, U4.3 (1IN+)
unnamed: R8.1, R9.2, U2.5 (2IN+)
unnamed: U4.6 (2IN-), U4.7 (2OUT)
unnamed: R10.1, R11.2, U3.5 (2IN+)
unnamed: R14.2, U$1.IN (G)
OUTPUT9: Q3.2 (S), R17.1, VCC.5
OUTPUT9-1: Q3.3 (D), R13.2, R14.1, R18.1
OUTPUT9-OUT: D7.A, D9.3, TP6.1, U$1.GND (D)
OUTPUT10: Q4.2 (S), R19.1, VCC.4
OUTPUT10-OUT: D10.3, Q4.3 (D), R20.1, TP7.1
RX: TX/RX.2, VCC.7
SCL: EZO_BOARD1.RX, EZO_BOARD2.RX, EZO_BOARD3.RX, EZO_BOARD4.RX, J1.2, Q2.3 (D), R21.1
SCL_LV: D0.6, Q2.2 (S), R16.1
SDA: EZO_BOARD1.TX, EZO_BOARD2.TX, EZO_BOARD3.TX, EZO_BOARD4.TX, J1.1, Q1.3 (D), R1.1, R15.1
SDA_LV: D0.5, Q1.2 (S), R12.1
TX: D0.7, TX/RX.1
VCC: +5V.1, D1.1, D2.1, D3.1, D8.1, D10.1, DO.1, EZO_BOARD1.VCC, EZO_BOARD2.VCC, EZO_BOARD3.VCC, EZO_BOARD4.VCC, J1.5, R1.2, R15.2, R18.2, R20.2, R21.2, VCC.1
VCC_1: +3.3V.1, Q1.1 (G), Q2.1 (G), Q3.1 (G), Q4.1 (G), R12.2, R16.2, R17.2, R19.2, TX/RX.3, VCC.3
VCC_2: +12V.1, D7.C, D9.1, J1.6, U2.8 (VCC), U3.8 (VCC), U4.8 (VCC)

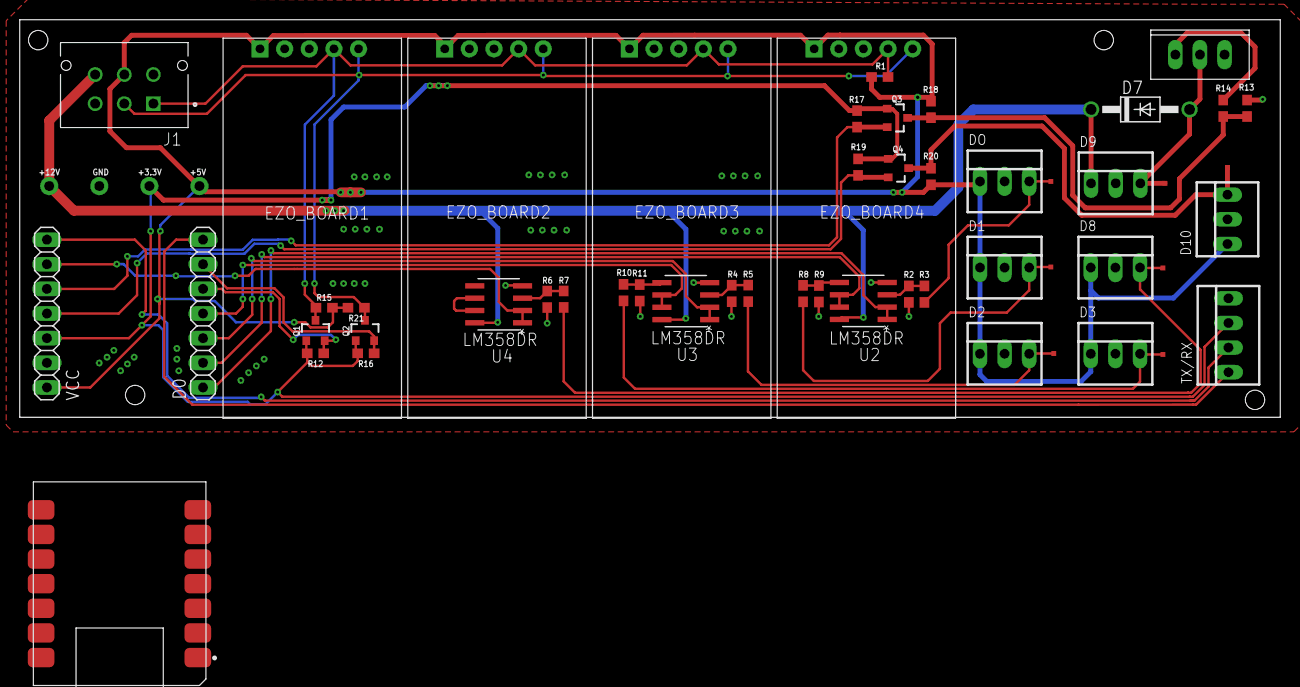
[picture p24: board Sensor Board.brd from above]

Board: 2 copper layers, 130.0 x 41.0 mm, 57 parts (0 on the bottom side), 32 nets.

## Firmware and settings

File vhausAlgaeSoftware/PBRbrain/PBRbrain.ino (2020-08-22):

#include <Wire.h>
#include <ArduinoJson.h>
#include <VarSpeedServo.h>

VarSpeedServo dumpServo1;
VarSpeedServo dumpServo2;
VarSpeedServo harvestServo;
int dumpServo1Pin = 11;  //input
int dumpServo2Pin = 10;  //input
int harvestServoPin = 9;  //input
byte servoPower = 12;
int dumpServo1LP = 0;
int dumpServo2LP = 0;
int harvestServoLP = 0;
int dumpServo1Closed = 0;
int dumpServo2Closed = 0;
int harvestServoClosed = 0;
int dumpServo1Open = 0;
int dumpServo2Open = 0;
int harvestServoOpen = 0;
byte servoMoved = 0;
unsigned long lastServoOff;
const long servoOffDelay = 4000;

unsigned long startMillis;
unsigned long lastStartDelay = 0;
const long StartDelay = 3000;

byte checkTime = 0;
unsigned long countDownFrom = 20160;
unsigned long remainingCycle = 0;
byte startHarvestFlag = 0;
unsigned long cycleCurrentMillis;
unsigned long lastCycleDelay = 0;
unsigned long cyleDelay = 60000;

int airPowerPin = 3;   //input

unsigned long pbrWaterLowMillis;
unsigned long pbrWaterFullMillis;
const int waterLevelPBR = A1;  //input
const int waterPumpPBR = 7;  //Output

const int waterPumpChiller = 6;

unsigned long lastPumpOn = 0;
unsigned long pumpOffDelay = 100;
unsigned long lastPumpOff = 0;
unsigned long pumpOnDelay = 100;

int phDownPump = 45;  //Output
int phUpPump = 46;  //Output
unsigned long lastpHDownDelay = 0;
unsigned long pHDownDelay = 20000;
unsigned long lastpHUpDelay = 0;
unsigned long pHUpDelay = 20000;
unsigned long lastpHOffDelay = 0;
unsigned long pHOffDelay = 0;
unsigned long pHDowncurrentMillis;
unsigned long pHUpcurrentMillis;
unsigned long pHOffcurrentMillis;
byte pumpOn = 0;

int lp1_1 = 26;  //input
int lp1_2 = 27;
int lp1_3 = 28;
int lp1_4 = 29;
int lp2_1 = 30;
int lp2_2 = 31;
int lp2_3 = 32;
int lp2_4 = 33;
unsigned long luxOncurrentMillis;
unsigned long lastLuxOnDelay = 0;
unsigned long luxOnDelay = 15000;
unsigned long luxOffcurrentMillis;
unsigned long lastLuxOffDelay = 0;
unsigned long luxOffDelay = 15000;
byte lightingON = 0;

int chillOn = 48;  //input
int chillErr = 46;
int chillEmpty = 44;
byte chillState = 0;
int heatOn = 4;  //input
byte heatState = 0;

//I2C Slave Address
const int BrainAdd = 3;
const int SensorBoardAdd = 8;
const int DOmeterAdd = 97;
const int RTDmeterAdd = 102;
const int PHmeterAdd = 99;
float b3;

char input[1200];
// I2C Commands
char command = 0;
enum {
  CMD_Pi01 = 1,
  CMD_Pi02 = 2,
  CMD_Pi03 = 3,
  CMD_Pi04 = 4,
  CMD_Pi05 = 5,
  CMD_Pi06 = 6,
  CMD_Pi07 = 7,
  CMD_Pi08 = 8,
  CMD_Pi09 = 9,
  CMD_Pi010 = 10,

  CMD_SB01 = 11,
  CMD_SB02 = 12,
  CMD_SB03 = 13
};

char Atlasdata[20];
float ph_data, do_data, rtd_data;
const int readingDelay = 800;

const size_t capacityIn = JSON_OBJECT_SIZE(58) + 1080;
DynamicJsonDocument docIn(capacityIn);
char json[capacityIn];
DynamicJsonDocument docOut(capacityIn);

byte pbr_auto_man_in, pbr_start_stop_in, light_auto_man_in, light_panel_1_in, lp1_1_in, lp1_2_in,
     lp1_3_in, lp1_4_in, light_panel_2_in, lp2_1_in, lp2_2_in, lp2_3_in, lp2_4_in, temp_auto_man_in,
     temp_start_stop_in, air_auto_man_in, air_start_stop_in, dose_auto_man_in, dose_start_stop_in,
     dose_ph_up_in, dose_ph_down_in, dose_nut_in, dose_sample_in, dose_top_up_in, harvset_auto_mann_in,
     harvest_start_stop_in;
char pbr_status_in, pbr_alarm_in;

float lux_sv_in, lux_pv_in, ph_sv_in, ph_pv_in, do_sv_in, do_pv_in, temp_sv_in, temp_pv_in, turbity_sv_in, turbity_pv_in,
      coil1_sv_in, coil1_pv_in, coil2_sv_in, coil2_pv_in, chiller_temp_sv_in, chiller_temp_pv_in,
      co2_in_sv_in, co2_in_pv_in, co2_out_sv_in, co2_out_pv_in, pressure_sv_in, pressure_pv_in,
      press_valve_sv_in, press_valve_pv_in, dump1_valve_sv_in, dump1_valve_pv_in,
      dump2_valve_sv_in, dump2_valve_pv_in;
long pbr_cycle_length_in, pbr_cycle_remaining_in;

unsigned long EzoMillis;
unsigned long previousEzoMillis;
int ezoDelay = 3000;

int sb1 = 0;
int sb2 = 0;
int sb3 = 0;

int sb4 = 0;
int sb5 = 0;
int sb6 = 0;

int sb7 = 0;
int sb8 = 0;
int sb9 = 0;

int startCycleFlag = 0;

void setup() {
  // put your setup code here, to run once:

  Wire.begin(BrainAdd);
  Wire.onReceive(receiveEvent);
  //Wire.onRequest(requestEvent);

  Serial.begin(57600);

  dumpServo1.attach(dumpServo1Pin);  // attaches the servo on pin 9 to the servo object
  dumpServo1.write(0, 125, false); // (Intial pos,Speed(0-255),wait for servo or keep going(true/false))
  dumpServo2.attach(dumpServo2Pin);  // attaches the servo on pin 9 to the servo object
  dumpServo2.write(0, 125, true);
  harvestServo.attach(harvestServoPin);  // attaches the servo on pin 9 to the servo object
  harvestServo.write(0, 125, true);
  pinMode(servoPower, OUTPUT);
  digitalWrite(servoPower, LOW);

  pinMode(airPowerPin, OUTPUT);
  digitalWrite(airPowerPin, LOW);

  pinMode(waterLevelPBR, INPUT);
  pinMode(waterPumpPBR, OUTPUT);
  digitalWrite(waterPumpPBR, LOW);

  pinMode(phDownPump, INPUT);
  pinMode(phUpPump, OUTPUT);
  digitalWrite(phDownPump, LOW);
  digitalWrite(phUpPump, LOW);

  pinMode(chillOn, OUTPUT);
  pinMode(heatOn, OUTPUT);
  digitalWrite(chillOn, LOW);
  digitalWrite(heatOn, LOW);

  pinMode(lp1_1, OUTPUT);
  pinMode(lp1_2, OUTPUT);
  pinMode(lp1_3, OUTPUT);
  pinMode(lp1_4, OUTPUT);
  pinMode(lp2_1, OUTPUT);
  pinMode(lp2_2, OUTPUT);
  pinMode(lp2_3, OUTPUT);
  pinMode(lp2_4, OUTPUT);
  digitalWrite(lp1_1, LOW);
  digitalWrite(lp1_2, LOW);
  digitalWrite(lp1_3, LOW);
  digitalWrite(lp1_4, LOW);
  digitalWrite(lp2_1, LOW);
  digitalWrite(lp2_2, LOW);
  digitalWrite(lp2_3, LOW);
  digitalWrite(lp2_4, LOW);
}

//////////////////////////////////////////////////////////
//              Handles incoming data                   //
//////////////////////////////////////////////////////////
void receiveEvent (int howMany) {
  command = Wire.read ();  // remember command for when we get request
}

//////////////////////////////////////////////////////////
//              Handels outgoing data                   //
//////////////////////////////////////////////////////////
void requestEvent ()  {
  switch (command)  {
      //case CMD_SB01:      dumpSB01(); break;  // send 1st Packet
      //case CMD_SB02:      dumpSB02(); break;  // send 2nd Packet
      //case CMD_SB03:      dumpSB03(); break;  // send 3rd Packet
  }

}

void loop() {
  // put your main code here, to run repeatedly:
  RequestSensorBoard();
  RequestMeterData();
  //mergeDocJSON();
  if (Serial.available() > 0)  {
    RecievePiUpdate();
    Cycle();
    sendBack();
  }
  if (servoMoved == 1)  {
    ServoPowerOffDelay();
  }
}

void Cycle()  {
  autoCycle();                  //Run Auto Cycle
  //manualControl();              //Run Manual Commands
}

void autoCycle()  {
  if (pbr_auto_man_in == 1 && pbr_start_stop_in == 1) {
    startMillis = millis();
    if (startMillis - lastStartDelay >= StartDelay) {
      // save the last time you blinked the LED
      lastStartDelay = startMillis;
      startCycleFlag = 1;
    }
  }
  else  {
    startCycleFlag = 0;
  }

  if (startCycleFlag == 1)  {
    checkTimeRemaining(); //Check Time Remaining and Update
    setServosClosed();    //Set Dump Valves Are Closed
    checkAir();           //Check That Air Is On
    checkWaterLevel();    //Check Water Level and Top Up
    checkPh();            //Check pH Level
    //checkTemp();          //Check Tempreture
    //checkLighting();      //Check Light Status
    reportStatus();

  }
}
void checkTimeRemaining()   {
  //check time at start of cycle

  if (startCycleFlag == 1) {
    if (checkTime == 0) {
      countDownFrom = pbr_cycle_length_in;
      remainingCycle = countDownFrom;
      pbr_cycle_remaining_in = remainingCycle;
      checkTime = 1;
    }
    cycleCurrentMillis = millis();
    if (cycleCurrentMillis - lastCycleDelay >= cyleDelay && startCycleFlag == 1) {
      // save the last time you blinked the LED
      lastCycleDelay = cycleCurrentMillis;
      remainingCycle = --remainingCycle;
      pbr_cycle_remaining_in = remainingCycle;
    }

    if (startCycleFlag == 1 && pbr_cycle_remaining_in == 0) {
      startHarvestFlag = 1;
    }
  }
}

void setServosClosed()  {

  if (startCycleFlag == 1 && harvset_auto_mann_in == 1) {

    if (dumpServo1LP != dumpServo1Closed || dumpServo2LP != dumpServo2Closed )  {
      digitalWrite(servoPower, HIGH);
      dumpServo1.write(dumpServo1Closed, 125, false); // (Intial pos,Speed(0-255),wait for servo or keep going(true/false))
      dumpServo1LP = dumpServo1Closed;
      dump1_valve_sv_in = dumpServo1Closed;
      dump1_valve_pv_in = dumpServo1Closed;
      dumpServo2.write(dumpServo2Closed, 125, false);
      dumpServo2LP = dumpServo2Closed;
      dump2_valve_sv_in = dumpServo2Closed;
      dump2_valve_pv_in = dumpServo2Closed;
      //harvestServo.write(harvestServoClosed,125,false);
      //harvestServoLP = harvestServoClosed;
      //press_valve_sv_in = harvestServoClosed;
      //press_valve_pv_in = harvestServoClosed;
      servoMoved = 1;
    }
  }
}

void ServoPowerOffDelay() {
  unsigned long currentMillis = millis();
  if (currentMillis - lastServoOff >= servoOffDelay) {
    // save the last time you blinked the LED
    lastServoOff = currentMillis;
    digitalWrite(servoPower, LOW);
    servoMoved = 0;
  }
}

void checkAir() {
  if (startCycleFlag == 1 && air_auto_man_in == 1) {
    digitalWrite(airPowerPin, HIGH);
    air_start_stop_in = 1;
  }
}

void checkWaterLevel()  {
  if (startCycleFlag == 1 && dose_auto_man_in == 1) {
    int reading = digitalRead(waterLevelPBR);
    if (reading == 0) {
      pbrWaterLowMillis = millis();
      if (pbrWaterLowMillis - lastPumpOn >= pumpOnDelay) {
        // save the last time you blinked the LED
        lastPumpOn = pbrWaterLowMillis;
        digitalWrite(waterPumpPBR, HIGH);
        dose_top_up_in = 1;
      }
    }
    if (reading == 1) {
      pbrWaterFullMillis = millis();
      if (pbrWaterFullMillis - lastPumpOff >= pumpOffDelay) {
        // save the last time you blinked the LED
        lastPumpOff = pbrWaterFullMillis;
        digitalWrite(waterPumpPBR, LOW);
        dose_top_up_in = 0;
      }
    }
  }
}

void checkPh()  {
  if (startCycleFlag == 1 && dose_auto_man_in == 1) {
    //int reading = ph_pv_in;
    if (ph_pv_in >= (ph_sv_in + 1)) {
      pHDowncurrentMillis = millis();
      if (pHDowncurrentMillis - lastpHDownDelay >= pHDownDelay) {
        // save the last time you blinked the LED
        lastpHDownDelay = pHDowncurrentMillis;
        digitalWrite(phDownPump, HIGH);
        dose_ph_down_in = 1;
        pumpOn = 1;
      }
    }

    if (ph_pv_in <= (ph_sv_in - 1)) {
      pHUpcurrentMillis = millis();
      if (pHUpcurrentMillis - lastpHUpDelay >= pHUpDelay) {
        // save the last time you blinked the LED
        lastPumpOff = pHUpcurrentMillis;
        digitalWrite(phUpPump, HIGH);
        dose_ph_up_in = 1;
        pumpOn = 1;
      }
    }
  }

  if (pumpOn == 1) {
    pHOffcurrentMillis = millis();
    if (pHOffcurrentMillis - lastpHOffDelay >= pHOffDelay) {
      // save the last time you blinked the LED
      lastpHOffDelay = pHOffcurrentMillis;
      digitalWrite(phUpPump, LOW);
      digitalWrite(phDownPump, LOW);
      dose_ph_up_in = 0;
      dose_ph_down_in = 0;
      pumpOn = 0;
    }
  }
}

void checkTemp()  {
  if (startCycleFlag == 1 && temp_auto_man_in == 1) {
    //int reading = ph_pv_in;
    if (temp_pv_in >= (temp_sv_in + 3) && chillState == 0) {
      digitalWrite(chillOn, HIGH);
      chillState = 1;
      temp_start_stop_in = 1;
    }
    if (temp_pv_in == (temp_sv_in) && chillState == 1) {
      digitalWrite(chillOn, LOW);
      chillState = 0;
      temp_start_stop_in = 0;
    }
    if (temp_pv_in <= (temp_sv_in - 3) && heatState == 0) {
      digitalWrite(heatOn, HIGH);
      heatState = 1;
      temp_start_stop_in = 1;
    }
    if (temp_pv_in == (temp_sv_in) && heatState == 1) {
      digitalWrite(heatOn, LOW);
      heatState = 0;
      temp_start_stop_in = 0;
    }
  }
}

void checkLighting()  {
  if (startCycleFlag == 1 && light_auto_man_in == 1) {

    //light cycle time length
    //light cycle start time
    //Light cycle Off Time
    if (lux_pv_in >= lux_sv_in) {
      luxOncurrentMillis = millis();
      if (luxOncurrentMillis - lastLuxOnDelay >= luxOnDelay) {
        // save the last time you blinked the LED
        lastLuxOnDelay = luxOncurrentMillis;
        digitalWrite(lp1_1, HIGH);
        digitalWrite(lp1_2, HIGH);
        digitalWrite(lp1_3, HIGH);
        digitalWrite(lp1_4, HIGH);
        digitalWrite(lp2_1, HIGH);
        digitalWrite(lp2_2, HIGH);
        digitalWrite(lp2_3, HIGH);
        digitalWrite(lp2_4, HIGH);
        light_panel_1_in = 1;
        lp1_1_in = 1;
        lp1_2_in = 1;
        lp1_3_in = 1;
        lp1_4_in = 1;
        light_panel_2_in = 1;
        lp2_1_in = 1;
        lp2_2_in = 1;
        lp2_3_in = 1;
        lp2_4_in = 1;
        lightingON = 1;
      }
    }

    if (lux_pv_in <= (lux_sv_in - 10)) {
      luxOffcurrentMillis = millis();
      if (luxOffcurrentMillis - lastLuxOffDelay >= luxOffDelay) {
        // save the last time you blinked the LED
        lastLuxOffDelay = luxOffcurrentMillis;
        digitalWrite(lp1_1, LOW);
        digitalWrite(lp1_2, LOW);
        digitalWrite(lp1_3, LOW);
        digitalWrite(lp1_4, LOW);
        digitalWrite(lp2_1, LOW);
        digitalWrite(lp2_2, LOW);
        digitalWrite(lp2_3, LOW);
        digitalWrite(lp2_4, LOW);
        light_panel_1_in = 0;
        lp1_1_in = 0;
        lp1_2_in = 0;
        lp1_3_in = 0;
        lp1_4_in = 0;
        light_panel_2_in = 0;
        lp2_1_in = 0;
        lp2_2_in = 0;
        lp2_3_in = 0;
        lp2_4_in = 0;
        lightingON = 0;
      }
    }
  }
}

void reportStatus() {
  if (startCycleFlag == 1)  {
    pbr_status_in = 1;
    pbr_alarm_in = 2;

  }
}

void manualControl() {

  /*unsigned long currentMillis = millis();
    dump1_valve_pv_in = map(dump1_valve_sv_in, 0, 100, 0, 255);
    dumpServo1LP = dump1_valve_sv_in;
    dump2_valve_pv_in = map(dump2_valve_sv_in, 0, 100, 0, 255);
    dumpServo2LP = dump2_valve_sv_in;
    press_valve_pv_in = map(press_valve_sv_in, 0, 100, 0, 255);
    harvestServoLP = press_valve_sv_in;
  */
  if (pbr_auto_man_in == 0 || pbr_start_stop_in == 0) {
    pbr_start_stop_in = 0;
    startCycleFlag = 0;
  }

  if (light_auto_man_in == 0) {
    if (light_panel_1_in == 1) {
      digitalWrite(lp1_1, HIGH);
      digitalWrite(lp1_2, HIGH);
      digitalWrite(lp1_3, HIGH);
      digitalWrite(lp1_4, HIGH);
      lp1_1_in = 1;
      lp1_2_in = 1;
      lp1_3_in = 1;
      lp1_4_in = 1;
    }
    if (light_panel_2_in == 1) {
      digitalWrite(lp2_1, HIGH);
      digitalWrite(lp2_2, HIGH);
      digitalWrite(lp2_3, HIGH);
      digitalWrite(lp2_4, HIGH);
      lp2_1_in = 1;
      lp2_2_in = 1;
      lp2_3_in = 1;
      lp2_4_in = 1;
    }
    if (light_panel_1_in == 0) {
      digitalWrite(lp1_1, LOW);
      digitalWrite(lp1_2, LOW);
      digitalWrite(lp1_3, LOW);
      digitalWrite(lp1_4, LOW);
      lp1_1_in = 0;
      lp1_2_in = 0;
      lp1_3_in = 0;
      lp1_4_in = 0;
    }
    if (light_panel_2_in == 0) {
      digitalWrite(lp2_1, LOW);
      digitalWrite(lp2_2, LOW);
      digitalWrite(lp2_3, LOW);
      digitalWrite(lp2_4, LOW);
      lp2_1_in = 0;
      lp2_2_in = 0;
      lp2_3_in = 0;
      lp2_4_in = 0;
    }
  }

  if (dose_auto_man_in == 1)  {
    dose_ph_up_in = 0;
    dose_ph_down_in = 0;
    dose_nut_in = 0;
    dose_sample_in = 0;
    dose_top_up_in = 0;
  }

}

void RecievePiUpdate() {
  deserializeJson(docIn, Serial);
  pbr_auto_man_in = docIn["pbr_auto_man"];
  pbr_start_stop_in = docIn["pbr_start_stop"];
  light_auto_man_in = docIn["light_auto_man"];
  light_panel_1_in = docIn["lp_1"];
  lp1_1_in = docIn["lp1_1"];
  lp1_2_in = docIn["lp1_2"];
  lp1_3_in = docIn["lp1_3"];
  lp1_4_in = docIn["lp1_4"];
  light_panel_2_in = docIn["lp_2"];
  lp2_1_in = docIn["lp2_1"];
  lp2_2_in = docIn["lp2_2"];
  lp2_3_in = docIn["lp2_3"];
  lp2_4_in = docIn["lp2_4"];
  temp_auto_man_in = docIn["temp_auto_man"];
  temp_start_stop_in = docIn["temp_start_stop:"];
  air_auto_man_in = docIn["air_auto_man"];
  air_start_stop_in = docIn["air_start_stop"];
  dose_auto_man_in = docIn["dose_auto_man"];
  dose_start_stop_in = docIn["dose_start_stop"];
  dose_ph_up_in = docIn["dose_ph_up"];
  dose_ph_down_in = docIn["dose_ph_down"];
  dose_nut_in = docIn["dose_nut"];
  dose_sample_in = docIn["dose_sample"];
  dose_top_up_in = docIn["dose_top_up"];
  harvset_auto_mann_in = docIn["harvset_auto_mann"];
  harvest_start_stop_in = docIn["harvest_start_stop"];

  pbr_cycle_length_in = docIn["pbr_cycle_length"];
  pbr_cycle_remaining_in = docIn["pbr_cycle_remaining"];

  lux_sv_in = docIn["lux_sv"];
  lux_pv_in = docIn["lux_pv"];
  ph_sv_in = docIn["ph_sv"];
  ph_pv_in = docIn["ph_pv"];
  do_sv_in = docIn["do_sv"];
  do_pv_in = docIn["do_pv"];
  temp_sv_in = docIn["temp_sv"];
  temp_pv_in = docIn["temp_pv"];
  turbity_sv_in = docIn["turbity_sv"];
  turbity_pv_in = docIn["turbity_pv"];
  coil1_sv_in = docIn["coil1_sv"];
  coil1_pv_in = docIn["coil1_pv"];
  coil2_sv_in = docIn["coil2_sv"];
  coil2_pv_in = docIn["coil2_pv"];
  chiller_temp_sv_in = docIn["chiller_temp_sv"];
  chiller_temp_pv_in = docIn["chiller_temp_pv"];
  co2_in_sv_in = docIn["co2_in_sv"];
  co2_in_pv_in = docIn["co2_in_pv"];
  co2_out_sv_in = docIn["co2_out_sv"];
  co2_out_pv_in = docIn["co2_out_pv"];
  pressure_sv_in = docIn["pressure_sv"];
  pressure_pv_in = docIn["pressure_pv"];
  press_valve_sv_in = docIn["press_valve_sv"];
  press_valve_pv_in = docIn["press_valve_pv"];
  dump1_valve_sv_in = docIn["dump1_valve_sv"];
  dump1_valve_pv_in = docIn["dump1_valve_pv"];
  dump2_valve_sv_in = docIn["dump2_valve_sv"];
  dump2_valve_pv_in = docIn["dump2_valve_pv"];
  pbr_status_in = docIn["pbr_status"];
  pbr_alarm_in = docIn["pbr_alarm"];
}

void sendBack() {
  docOut["pbr_auto_man"] = pbr_auto_man_in;
  docOut["pbr_start_stop"] = pbr_start_stop_in;
  docOut["light_auto_man"] = light_auto_man_in;
  docOut["lp_1"] = light_panel_1_in;
  docOut["lp1_1"] = lp1_1_in;
  docOut["lp1_2"] = lp1_2_in;
  docOut["lp1_3"] = lp1_3_in;
  docOut["lp1_4"] = lp1_4_in;
  docOut["lp_2"] = light_panel_2_in;
  docOut["lp2_1"] = lp2_1_in;
  docOut["lp2_2"] = lp2_2_in;
  docOut["lp2_3"] = lp2_3_in;
  docOut["lp2_4"] = lp2_4_in;
  docOut["temp_auto_man"] = temp_auto_man_in;
  docOut["temp_start_stop"] = temp_start_stop_in;
  docOut["air_auto_man"] = air_auto_man_in;
  docOut["air_start_stop"] = air_start_stop_in;
  docOut["dose_auto_man"] = dose_auto_man_in;
  docOut["dose_start_stop"] = dose_start_stop_in;
  docOut["dose_ph_up"] = dose_ph_up_in;
  docOut["dose_ph_down"] = dose_ph_down_in;
  docOut["dose_nut"] = dose_nut_in;
  docOut["dose_sample"] = dose_sample_in;
  docOut["dose_top_up"] = dose_top_up_in;
  docOut["harvset_auto_mann"] = harvset_auto_mann_in;
  docOut["harvest_start_stop"] = harvest_start_stop_in;
  docOut["pbr_cycle_length"] = pbr_cycle_length_in;
  docOut["pbr_cycle_remaining"] = pbr_cycle_remaining_in;
  docOut["lux_sv"] = lux_sv_in;
  docOut["lux_pv"] = sb4;
  docOut["ph_sv"] = ph_sv_in;
  docOut["ph_pv"] = sb1;
  docOut["do_sv"] = do_sv_in;
  docOut["do_pv"] = sb3;
  docOut["temp_sv"] = temp_sv_in;
  docOut["temp_pv"] = sb2;
  docOut["turbity_sv"] = turbity_sv_in;
  docOut["turbity_pv"] = turbity_pv_in;
  docOut["coil1_sv"] = coil1_sv_in;
  docOut["coil1_pv"] = coil1_pv_in;
  docOut["coil2_sv"] = coil2_sv_in;
  docOut["coil2_pv"] = coil2_pv_in;
  docOut["chiller_temp_sv"] = chiller_temp_sv_in;
  docOut["chiller_temp_pv"] = chiller_temp_pv_in;
  docOut["co2_in_sv"] = co2_in_sv_in;
  docOut["co2_in_pv"] = co2_in_pv_in;
  docOut["co2_out_sv"] = co2_out_sv_in;
  docOut["co2_out_pv"] = sb7;
  docOut["pressure_sv"] = pressure_sv_in;
  docOut["pressure_pv"] = pressure_pv_in;
  docOut["press_valve_sv"] = press_valve_sv_in;
  docOut["press_valve_pv"] = press_valve_pv_in;
  docOut["dump1_valve_sv"] = dump1_valve_sv_in;
  docOut["dump1_valve_pv"] = dump1_valve_pv_in;
  docOut["dump2_valve_sv"] = dump2_valve_sv_in;
  docOut["dump2_valve_pv"] = dump2_valve_pv_in;
  docOut["pbr_status"] = pbr_status_in;
  docOut["pbr_alarm"] = pbr_alarm_in;
  serializeJson(docOut, Serial); //Return Current Readings
  Serial.println();
}

//////////////////////////////////////////////////////////
//              Read Sensor Board data and              //
//                   combined for use                   //
//////////////////////////////////////////////////////////
void RequestSensorBoard() {
  const size_t capacitySen = JSON_OBJECT_SIZE(3) + 20;
  DynamicJsonDocument docSen(300);
  if (Wire.requestFrom (SensorBoardAdd, capacitySen) == 0) {
    //Use to throw an error need to think about this ;/
    //Serial.println("Sensor Board Error::No reply");
  }
  else  {
    sendCommand (SensorBoardAdd, CMD_SB01, capacitySen);
    char json[capacitySen];
    DynamicJsonDocument doc1(capacitySen);
    deserializeJson(doc1, Wire);
    sb1 = doc1["s1"]; // 10
    sb2 = doc1["s2"]; // 11
    sb3 = doc1["s3"]; // 23

    sendCommand (SensorBoardAdd, CMD_SB02, capacitySen);
    DynamicJsonDocument doc2(capacitySen);
    deserializeJson(doc2, Wire);
    sb4 = doc2["s4"]; // 10
    sb5 = doc2["s5"]; // 11
    sb6 = doc2["s6"]; // 23

    sendCommand (SensorBoardAdd, CMD_SB03, capacitySen);
    DynamicJsonDocument doc3(capacitySen);
    deserializeJson(doc3, Wire);
    sb7 = doc3["s7"]; // 10
    sb8 = doc3["s8"]; // 11
    sb9 = doc3["s9"]; // 23

    //Combine messages for use
    merge(docSen.as<JsonVariant>(), doc1.as<JsonVariant>());
    merge(docSen.as<JsonVariant>(), doc2.as<JsonVariant>());
    merge(docSen.as<JsonVariant>(), doc3.as<JsonVariant>());
    //serializeJsonPretty(doc, Serial);
  }

}
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

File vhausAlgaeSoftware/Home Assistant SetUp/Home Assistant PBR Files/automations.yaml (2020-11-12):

# Configure a default setup of Home Assistant (frontend, api, etc)
default_config:

# Text to speech
tts:
  - platform: google_translate

group: !include groups.yaml
automation: !include automations.yaml
script: !include scripts.yaml
scene: !include scenes.yaml


mqtt:
    broker: 192.168.0.200
    username: !secret mqttUserName
    password: !secret mqttPassword
    
switch:
  - platform: mqtt
    name: "Cycle Auto/Manual"
    state_topic: "pbr/pbrAM/status"
    command_topic: "pbr/pbrAM/switch"
    payload_on: "ON"
    payload_off: "OFF"
  - platform: mqtt
    name: "Cycle Start/Stop"
    state_topic: "pbr/pbrSS/status"
    command_topic: "pbr/pbrSS/switch"
    payload_on: "ON"
    payload_off: "OFF"
  - platform: mqtt
    name: "Lighting Auto/Manual"
    state_topic: "pbr/lightAM/status"
    command_topic: "pbr/lightAM/switch"
    payload_on: "ON"
    payload_off: "OFF"
    optimistic: false    
  - platform: mqtt
    name: "Light Panel 1"
    state_topic: "pbr/lp1/status"
    command_topic: "pbr/lp1/switch"
    payload_on: "ON"
    payload_off: "OFF"
    optimistic: false
  - platform: mqtt
    name: "Light Panel 1_1"
    state_topic: "pbr/lp1_1/status"
    command_topic: "pbr/lp1_1/switch"
    payload_on: "ON"
    payload_off: "OFF"
    optimistic: false
  - platform: mqtt
    name: "Light Panel 1_2"
    state_topic: "pbr/lp1_2/status"
    command_topic: "pbr/lp1_2/switch"
    payload_on: "ON"
    payload_off: "OFF"
    optimistic: false
  - platform: mqtt
    name: "Light Panel 1_3"
    state_topic: "pbr/lp1_3/status"
    command_topic: "pbr/lp1_3/switch"
    payload_on: "ON"
    payload_off: "OFF"
    optimistic: false
  - platform: mqtt
    name: "Light Panel 1_4"
    state_topic: "pbr/lp1_4/status"
    command_topic: "pbr/lp1_4/switch"
    payload_on: "ON"
    payload_off: "OFF"
    optimistic: false
#Lighting Control
  - platform: mqtt
    name: "Light Panel 2"
    state_topic: "pbr/lp2/status"
    command_topic: "pbr/lp2/switch"
    payload_on: "ON"
    payload_off: "OFF"
    optimistic: false
  - platform: mqtt
    name: "Light Panel 2_1"
    state_topic: "pbr/lp2_1/status"
    command_topic: "pbr/lp2_1/switch"
    payload_on: "ON"
    payload_off: "OFF"
    optimistic: false
  - platform: mqtt
    name: "Light Panel 2_2"
    state_topic: "pbr/lp2_2/status"
    command_topic: "pbr/lp2_2/switch"
    payload_on: "ON"
    payload_off: "OFF"
    optimistic: false
  - platform: mqtt
    name: "Light Panel 2_3"
    state_topic: "pbr/lp2_3/status"
    command_topic: "pbr/lp2_3/switch"
    payload_on: "ON"
    payload_off: "OFF"
    optimistic: false
  - platform: mqtt
    name: "Light Panel 2_4"
    state_topic: "pbr/lp2_4/status"
    command_topic: "pbr/lp2_4/switch"
    payload_on: "ON"
    payload_off: "OFF"
    optimistic: false
#Chiller/Heater Control
  - platform: mqtt
    name: "Chiller Auto/Manual"
    state_topic: "pbr/chillAM/status"
    command_topic: "pbr/chillAM/switch"
    payload_on: "ON"
    payload_off: "OFF"
    optimistic: false
  - platform: mqtt
    name: "Chiller On/Off"
    state_topic: "pbr/chillSS/status"
    command_topic: "pbr/chillSS/switch"
    payload_on: "ON"
    payload_off: "OFF"
    optimistic: false
  - platform: mqtt
    name: "Cooling On/Off"
    state_topic: "pbr/chillOn/status"
    command_topic: "pbr/chillOn/switch"
    payload_on: "ON"
    payload_off: "OFF"
    optimistic: false
  - platform: mqtt
    name: "Heating On/Off"
    state_topic: "pbr/heatOn/status"
    command_topic: "pbr/heatOn/switch"
    payload_on: "ON"
    payload_off: "OFF"
    optimistic: false
#Air Control    
  - platform: mqtt
    name: "Air Auto/Manual"
    state_topic: "pbr/airAM/status"
    command_topic: "pbr/airAM/switch"
    payload_on: "ON"
    payload_off: "OFF"
    optimistic: false
  - platform: mqtt
    name: "Air On/Off"
    state_topic: "pbr/airSS/status"
    command_topic: "pbr/airSS/switch"
    payload_on: "ON"
    payload_off: "OFF"
    optimistic: false
    
  - platform: mqtt
    name: "Dosing Auto/Manual"
    state_topic: "pbr/doseAM/status"
    command_topic: "pbr/doseAM/switch"
    payload_on: "ON"
    payload_off: "OFF"
    optimistic: false
  - platform: mqtt
    name: "pH Up"
    state_topic: "pbr/phUp/status"
    command_topic: "pbr/phUp/switch"
    payload_on: "ON"
    payload_off: "OFF"
    optimistic: false
  - platform: mqtt
    name: "pH Down"
    state_topic: "pbr/phDown/status"
    command_topic: "pbr/phDown/switch"
    payload_on: "ON"
    payload_off: "OFF"
    optimistic: false
  - platform: mqtt
    name: "Nutriant Mix"
    state_topic: "pbr/nutMix/status"
    command_topic: "pbr/nutMix/switch"
    payload_on: "ON"
    payload_off: "OFF"
    optimistic: false
  - platform: mqtt
    name: "Sample Pump"
    state_topic: "pbr/samplePump/status"
    command_topic: "pbr/samplePump/switch"
    payload_on: "ON"
    payload_off: "OFF"
    optimistic: false
  - platform: mqtt
    name: "Top Up"
    state_topic: "pbr/topUp/status"
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

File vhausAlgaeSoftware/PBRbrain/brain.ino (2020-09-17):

#include <ArduinoJson.h>
#include <VarSpeedServo.h>

//Incoming Data doc from brainESP
const size_t capacity = JSON_OBJECT_SIZE(27) + 300;
DynamicJsonDocument brain(capacity);
const char* json[capacity];

const size_t capacity2 = JSON_OBJECT_SIZE(2);
DynamicJsonDocument docout(capacity2);


//Servo Setup Requirements
VarSpeedServo harvestServo1;
VarSpeedServo dumpServo1;
VarSpeedServo dumpServo2;


//Serial Readings
int lp1_1, lp1_2, lp1_3, lp1_4,
    lp2_1, lp2_2, lp2_3, lp2_4,
    chillSS, chillOn, heatOn, airSS,
    topUp, phDown, nutMix, sPump, hAM, hSS,
    servoOn, psv, d1sv, d2sv,
    pOpen, pClose, d1Open, d1Close, d2Open, d2Close;

//Lighting On/Off
int lp[]  = {0, 0, 0, 0, 0, 0, 0, 0};
int lpL[] = {0, 0, 0, 0, 0, 0, 0, 0};
int lighPin[] = {26, 27, 28, 29, 30, 31, 32, 33};

//Servo Control
int servoOnPin = 12, psvPin = 9, d1svPin = 11, d2svPin = 10;
int d1svL = 0, d2svL = 0, psvL = 0;
byte servoOnCheck = 0;
unsigned long d1Millis, lastD1Delay, d1Delay = 300;

unsigned long servoMillis, lastServoDelay, servoDelay = 1000;


//pumps
int wpCultPin = 6, wpTankPin = 7, wpHarvestPin = 2, airPumpPin = 3;

//Cooling
int heatPin = 4, coolPin = 5;


//Add Output Pins here inorder to set low/Set as Ouput in Setup
int outPutPins[] = {servoOnPin,
                    wpCultPin, wpTankPin, wpHarvestPin, airPumpPin,
                    heatPin, coolPin
                   };

unsigned long readMillis,lastreadOff,readDelay =5000;
int co2in;
void setup() {
  Serial.begin(115200);
  Serial3.begin(9600);

  //Set Lights
  for (byte i = 0; i < (sizeof(lighPin) / sizeof(lighPin[0])); i++) {
    pinMode(lighPin[i], OUTPUT);
    digitalWrite(lighPin[i], LOW);
  }
  //Set Outputs - taken from outPutPins[] array
  for (byte i = 0; i < (sizeof(outPutPins) / sizeof(outPutPins[0])); i++) {
    pinMode(outPutPins[i], OUTPUT);
    digitalWrite(outPutPins[i], LOW);
  }

  pinMode(A0, INPUT);    // sets the digital pin 7 as input

  
  //Set Servos
  harvestServo1.attach(psvPin);
  harvestServo1.write(0, 127, false);
  dumpServo1.attach(d1svPin);
  dumpServo1.write(0, 127, false);
  dumpServo2.attach(d2svPin);
  dumpServo2.write(0, 127, true);

}

void loop() {
  readBrainESP();
  turnONOffLights();
  servoControl();
  heatCool();
  airWaterPumps();
}

void readBrainESP() {
  if (Serial3.available() > 0) {
    deserializeJson(brain, Serial3);
    lp[0] = brain["lp1_1"];
    lp[1] = brain["lp1_2"];
    lp[2] = brain["lp1_3"];
    lp[3] = brain["lp1_4"];
    lp[4] = brain["lp2_1"];
    lp[5] = brain["lp2_2"];
    lp[6] = brain["lp2_3"];
    lp[7] = brain["lp2_4"];

    chillOn = brain["chillOn"];
    heatOn = brain["heatOn"];
    airSS = brain["airSS"];
    topUp = brain["topUp"];
    phDown = brain["phDown"];
    nutMix = brain["nutMix"];
    sPump = brain["sPump"];
    hAM = brain["hAM"];
    hSS = brain["hSS"];
    servoOn = brain["servoOn"];
    psv = brain["psv"];
    d1sv = brain["d1sv"];
    d2sv = brain["d2sv"];
    pOpen = brain["pOpen"];
    pClose = brain["pClose"];
    d1Open = brain["d1Open"];
    d1Close = brain["d1Close"];
    d2Open = brain["d2Open"];
    d2Close = brain["d2Close"];


    docout["sensor"] = co2in;
    docout["time"] = 1351824120;
    serializeJson(docout, Serial3);
    Serial3.println();
  }


  serializeJson(brain, Serial);
  Serial.println();
}

void turnONOffLights()  {
  for (byte i = 0; i < (sizeof(lighPin) / sizeof(lighPin[0])); i++) {
    if (lpL[i] != lp[i]) {
      if (lp[i] == 1) digitalWrite(lighPin[i], HIGH);
      else digitalWrite(lighPin[i], LOW);
      lpL[i] = lp[i];
    }
  }
}

void servoControl() {
  if (d1svL != d1sv) {
    digitalWrite(servoOnPin, HIGH);
    int mapSV = d1sv;
    mapSV = map(mapSV, 0, 100, d1Open, d1Close);
    dumpServo1.write(mapSV, 255, false);
    d1svL = d1sv;
    servoOnCheck = 1;
    servoMillis = millis();
    lastServoDelay = servoMillis;
  }
  if (d2svL != d2sv) {
    digitalWrite(servoOnPin, HIGH);
    int mapSV = d2sv;
    mapSV = map(mapSV, 0, 100, d2Open, d2Close);
    dumpServo2.write(mapSV, 255, false);
    d2svL = d2sv;
    servoOnCheck = 1;
    servoMillis = millis();
    lastServoDelay = servoMillis;
  }
  if (psvL != psv) {
    digitalWrite(servoOnPin, HIGH);
    int mapSV = psv;
    mapSV = map(mapSV, 0, 100, pOpen, pClose);
    harvestServo1.write(mapSV, 255, false);
    psvL = psv;
    servoOnCheck = 1;
    servoMillis = millis();
    lastServoDelay = servoMillis;
  }


  if (servoOnCheck == 1)  {
    servoMillis = millis();
    if (servoMillis - lastServoDelay >= servoDelay) {
      // save the last time you blinked the LED
      lastServoDelay = servoMillis;
      digitalWrite(servoOnPin, LOW);
      servoOnCheck = 0;
    }
  }
}

void heatCool() {
  if (chillOn == 1) {
    digitalWrite(coolPin, HIGH);
  }
  else if (chillOn == 0) {
    digitalWrite(coolPin, LOW);
  }
  if (heatOn == 1) {
    digitalWrite(heatPin, HIGH);
  }
  else if (heatOn == 0) {
    digitalWrite(heatPin, LOW);
  }

}

void airWaterPumps()  {
  if (airSS == 1) {
    digitalWrite(airPumpPin, HIGH);
  }
  else if (airSS == 0) {
    digitalWrite(airPumpPin, LOW);
  }
  if (topUp == 1) {
    digitalWrite(wpCultPin, HIGH);
  }
  else if (topUp == 0) {
    digitalWrite(wpCultPin, LOW);
  }
  if (hSS == 1) {
    digitalWrite(wpHarvestPin, HIGH);
  }
  else if (hSS == 0) {
    digitalWrite(wpHarvestPin, LOW);
  }
}

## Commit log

2020-02-22 Updated BOM ReadMe File
2020-02-22 updated board type
2020-08-27 updated arduino
2020-09-07 Brain Lighting Auto Fix
    [brainESP.ino]
2020-09-07 Added heat control
2020-09-07 Fixed Harvest Not Starting At Zero
    [brainESP.ino]
2020-09-09 Added servo comms
2020-09-11 updated sensor board
2020-09-17 fixed water auto/manual on/off
    [brain.ino, brainESP.ino]
2020-10-07 updated assembly file
2020-10-28 added 3D models
    [1 2 Flow Control Valve.step, 1 2 Two Piece Ball Valve BVS4B L T.step, 12MM Shut Off Valve.step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]
2020-10-28 added pcb
    [LED PCB.brd, LED PCB.sch, Main PCB.brd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]

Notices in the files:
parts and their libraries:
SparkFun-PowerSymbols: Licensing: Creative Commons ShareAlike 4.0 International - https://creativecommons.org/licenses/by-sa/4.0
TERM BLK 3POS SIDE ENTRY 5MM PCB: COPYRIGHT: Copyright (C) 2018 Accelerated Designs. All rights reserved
